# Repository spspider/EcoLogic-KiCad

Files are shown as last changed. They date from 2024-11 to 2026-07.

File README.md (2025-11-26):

# EcoLogic KiCad - ESP8266 Home Automation PCB

A professional-grade KiCad project for ESP8266-based home automation systems, designed for PCBWAY manufacturing and Home Assistant integration.

you can control your device throw this site:
[https://ecologic.pp.ua/iot-manager/](https://ecologic.pp.ua/iot-manager/)
Register as a new user and go to "Devices"

## 📋 Project Overview

This repository contains complete PCB designs for IoT home automation controllers using ESP8266 microcontrollers. The boards are optimized for controlling lights, home appliances, and other smart devices through Home Assistant.

### Key Features
- ESP8266-based design for WiFi connectivity
- Multiple relay outputs for appliance control
- PCBWAY-ready manufacturing files
- Home Assistant compatible
- Professional PCB layout with proper isolation
- SMD components for compact design

## 🖼️ Board Images

| Schematic | PCB Layout |
|---|---|
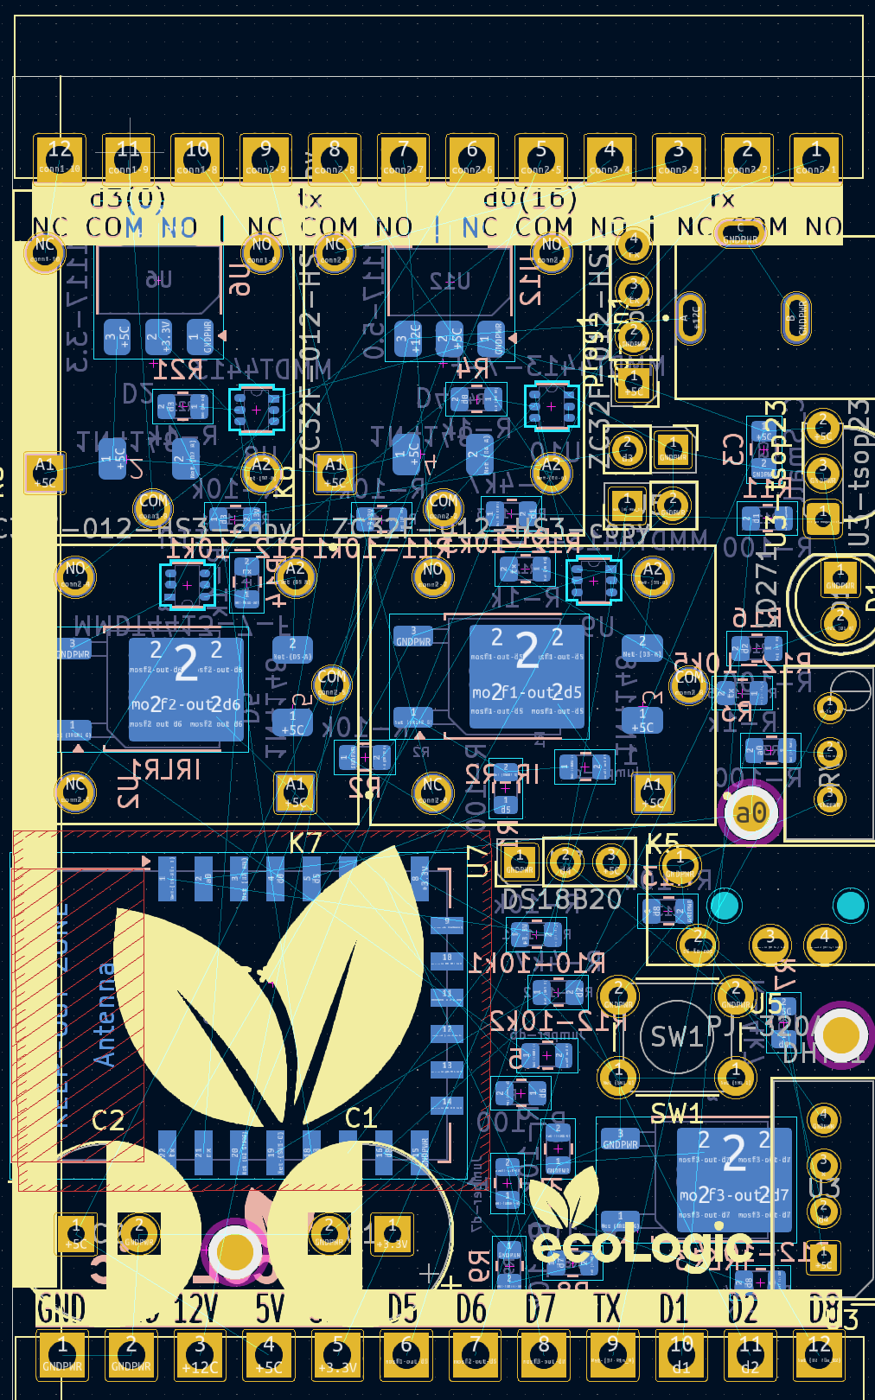
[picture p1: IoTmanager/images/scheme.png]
Schematic
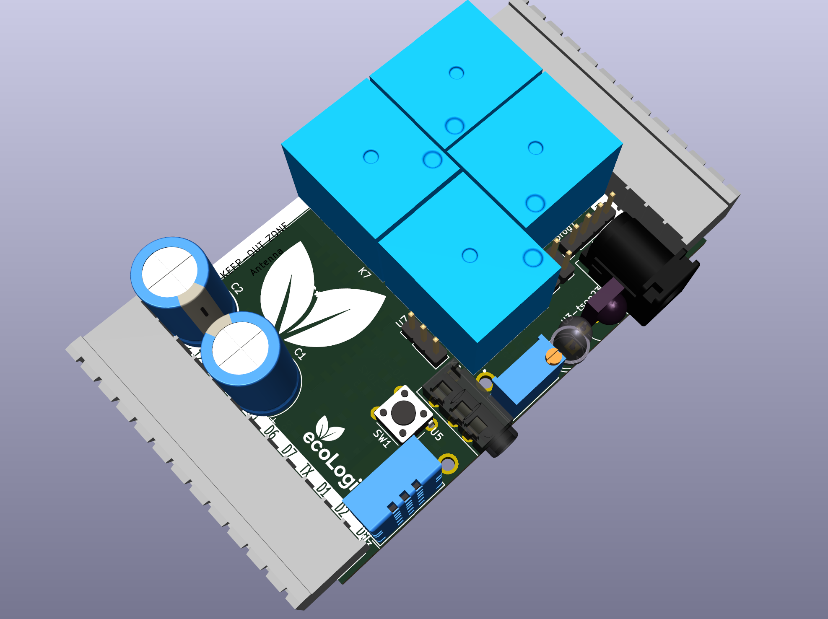
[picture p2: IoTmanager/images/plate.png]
PCB Top
|  |  |
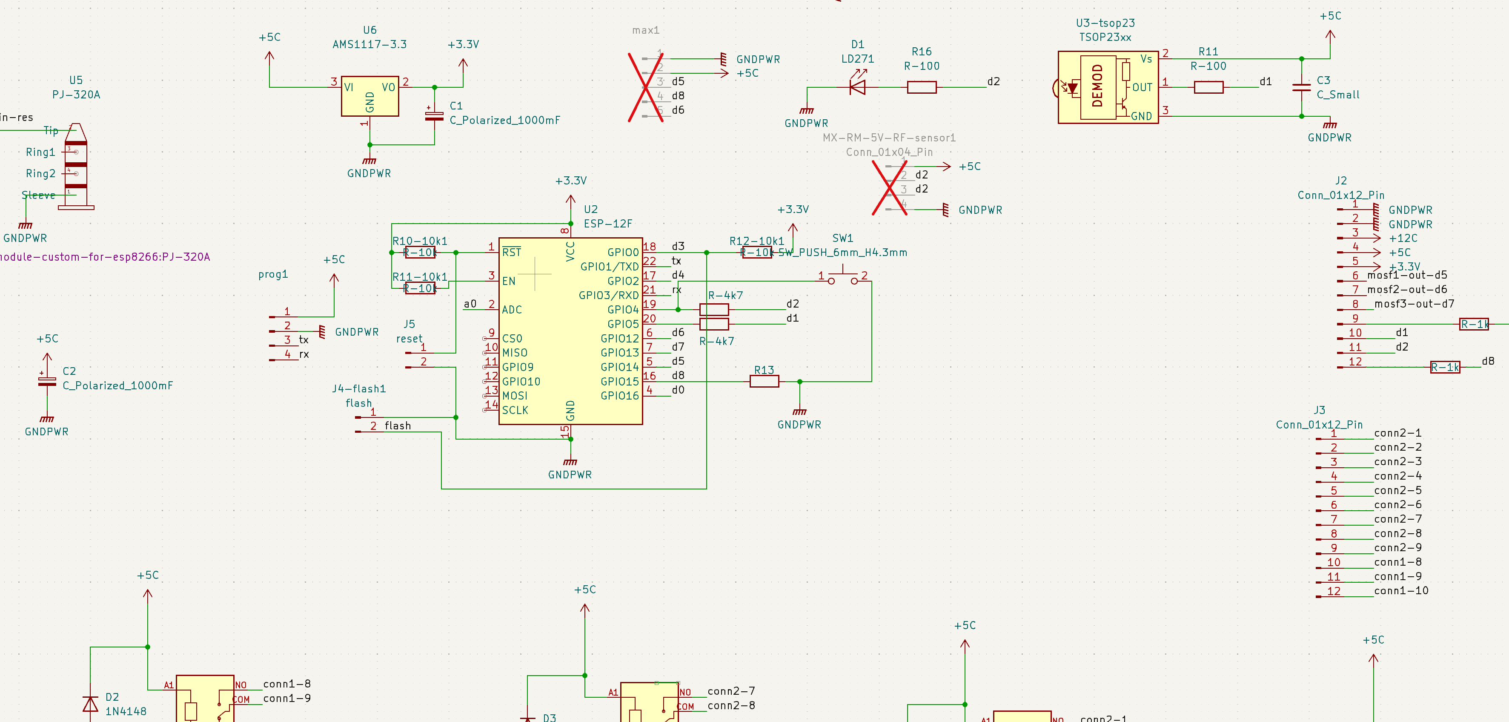
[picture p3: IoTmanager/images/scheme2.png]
Schematic v2
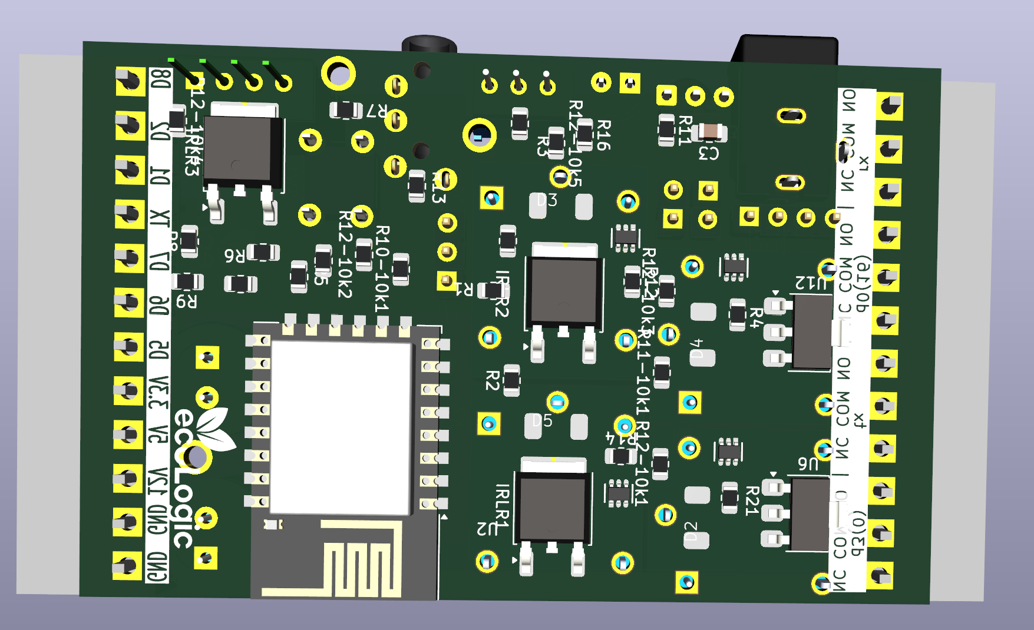
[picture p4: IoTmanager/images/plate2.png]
PCB Bottom
|  |  |

## 📁 Repository Structure

```
EcoLogic-KiCad/
├── IoTmanager/                    # Main project directory
│   ├── BOM-CPL/                   # Bill of Materials & Component Placement
│   │   ├── BOM.csv               # PCBWAY Bill of Materials
│   │   ├── CPL.xlsx              # Component Placement List
│   │   └── *.csv                 # Position files
│   ├── gerber/                    # Manufacturing files
│   │   ├── gerber.zip            # Complete gerber package
│   │   ├── *.gbr                 # Individual gerber layers
│   │   └── *.drl                 # Drill files
│   ├── images/                    # PCB and schematic images
│   ├── LCPCB/                     # PCBWAY templates
│   └── *.kicad_*                 # KiCad project files
└── README.md                      # This file
```

## 🔧 Bill of Materials (BOM)

| Reference | Component | Quantity | Description |
|---|---|---|---|
| U2 | ESP-12F | 1 | ESP8266 WiFi Module |
| U6 | AMS1117-3.3 | 1 | 3.3V Voltage Regulator |
| U12 | AMS1117-5.0 | 1 | 5.0V Voltage Regulator |
| U3 | DHT11 | 1 | Temperature & Humidity Sensor |
| U7 | DS18B20 | 1 | Temperature Sensor |
| U5 | PJ-320A | 1 | Audio Jack Connector |
| Q1,Q3,Q5,Q7 | MMBT5401 | 4 | PNP Transistors |
| Q2,Q4,Q6,Q8 | MMBT5551-npn | 4 | NPN Transistors |
| K3,K5,K6,K7 | ZC32F-012-HS3 | 4 | 12V Relays |
| D1 | LD271 | 1 | LED Indicator |
| D2,D3,D4,D5 | 1N4148 | 4 | Switching Diodes |
| C1,C2 | 1000µF | 2 | Polarized Capacitors |
| C4 | 10µF | 1 | Polarized Capacitor |
| C3 | 100nF | 1 | Ceramic Capacitor |
| R1,R5,R8,R11,R16 | 100Ω | 5 | Current Limiting Resistors |
| R3,R4,R12,R14-R19 | 1kΩ | 10 | Base Resistors |
| R2,R6,R9,R10,R13 | 10kΩ | 8 | Pull-up Resistors |
| R7 | 4.7kΩ | 1 | Pull-up Resistor |
| 33R1 | 33Ω | 1 | Current Limiting Resistor |
| J1 | Power Relay | 1 | Main Power Connector |
| J2,J3 | 12-Pin Connector | 2 | I/O Connectors |
| J4 | Flash Connector | 1 | Programming Interface |
| J5 | Reset Button | 1 | System Reset |
| SW1 | Push Button | 1 | 6mm Tactile Switch |
| Jumper-d5,d6,d7 | Jumpers | 3 | Configuration Jumpers |

## 🏭 PCBway Manufacturing Guide

### Step 1: Prepare Files
1. Download the complete `gerber.zip` from `IoTmanager/gerber/`
2. Get BOM file: `IoTmanager/BOM-CPL/BOM.csv`
3. Get CPL file: `IoTmanager/BOM-CPL/CPL.xlsx`

### Step 2: Upload to PCBWAY
1. Go to [www.pcbway.com](https://www.pcbway.com/QuickOrderOnline.aspx)
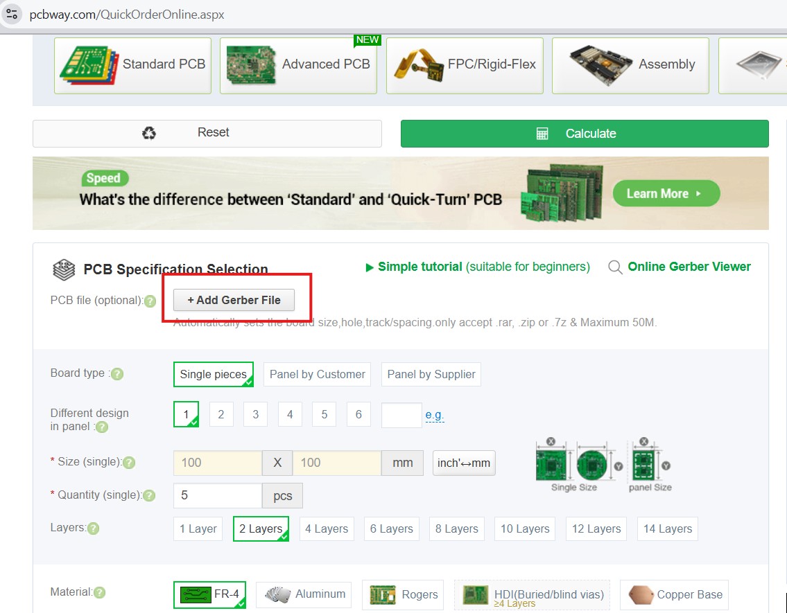
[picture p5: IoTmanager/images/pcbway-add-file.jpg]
pcbway add schematic

2. Click "Add gerber file" and upload `gerber2.zip`
3. Review PCB specifications, dont change anything:
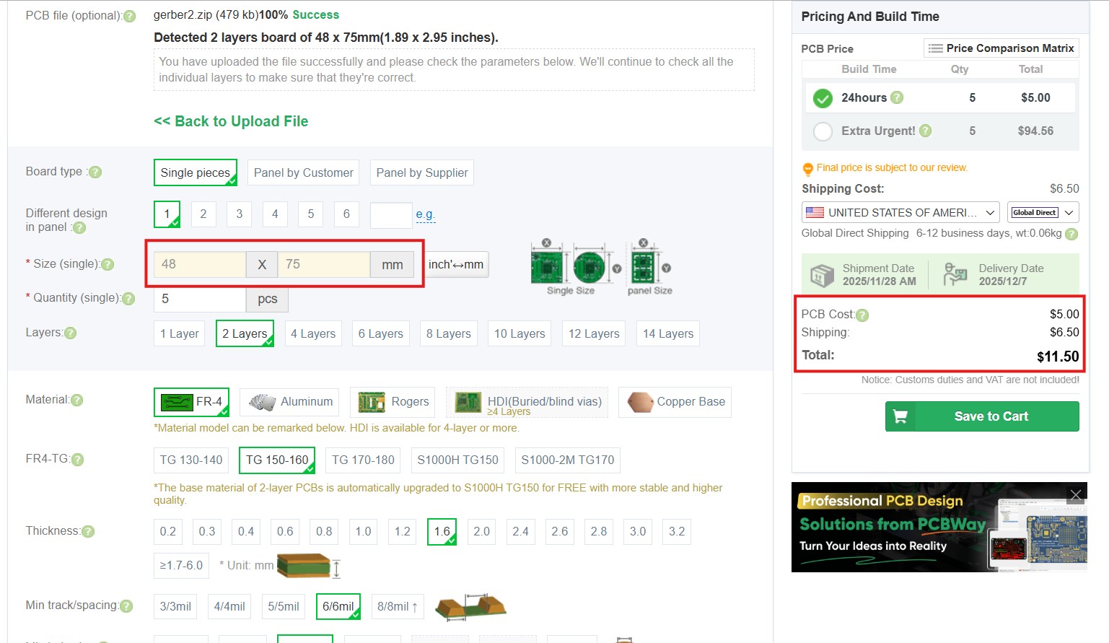
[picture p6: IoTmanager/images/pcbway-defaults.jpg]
review


   - **Layers**: 2
   - **Thickness**: 1.6mm
   - **Color**: Green (recommended)
   - **Surface Finish**: HASL (lead-free)

### Step 3: SMT Assembly (Optional)
1. Enable "SMT Assembly"
2. Upload BOM file (`BOM.csv`)
3. Upload CPL file (`CPL.xlsx`)
4. Review component placement
5. Confirm parts availability

### Step 4: Order
- Minimum quantity: 5 pieces
- Typical lead time: 2-5 days (PCB only)
- SMT assembly adds 3-5 days

## ⚡ Power Requirements

| Parameter | Value | Notes |
|---|---|---|
| Input Voltage | 5V DC | Via USB or external supply |
| Current Consumption | 80-200mA | Depends on relay states |
| Relay Switching | 10A @ 250V AC | Per relay channel |
| Logic Level | 3.3V | ESP8266 native |

## 🛠️ Assembly Tips

### Soldering Guidelines
- Use lead-free solder (SAC305 recommended)
- Soldering iron: 350°C for SMD components
- Use flux for better joints
- Solder ESP8266 module first

### Testing Procedure
1. **Visual Inspection**: Check for shorts and proper alignment
2. **Power Test**: Apply 5V and measure 3.3V rail
3. **Programming Test**: Upload basic blink sketch
4. **Relay Test**: Verify relay switching with multimeter

## 🚨 Safety Warnings

⚠️ **HIGH VOLTAGE WARNING**
- Relays switch mains voltage (110V/220V AC)
- Always disconnect power before wiring
- Use proper electrical enclosure
- Follow local electrical codes

⚠️ **ESD Precautions**
- Use anti-static wrist strap during assembly
- Store boards in anti-static bags
- Ground yourself before handling

## 📝 Version History

| Version | Date | Changes |
|---|---|---|
| v2 | 2025-07 | Improved routing, added protection circuits |
| v1 | 2025-05 | Initial release |

## 🤝 Contributing

1. Fork the repository
2. Create feature branch (`git checkout -b feature/improvement`)
3. Commit changes (`git commit -am 'Add improvement'`)
4. Push to branch (`git push origin feature/improvement`)
5. Create Pull Request

## 📄 License

This project is open-source hardware. Feel free to modify and distribute according to your needs.

## 🆘 Support & Donations

If this project helped you, consider supporting the development:



**Other ways to support:**
- ⭐ Star this repository
- 🐛 Report bugs and issues
- 💡 Suggest improvements
- 📖 Improve documentation
---

**Made with ❤️ for the Home Automation Community**

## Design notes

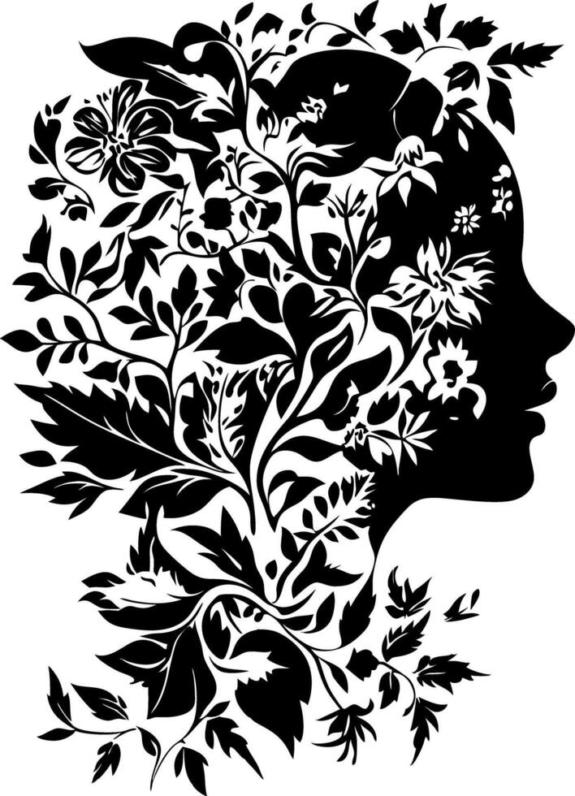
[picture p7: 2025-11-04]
IoTmanager/images/floral-silhouette-human-profile-intricate-botanical-design-for-art-and-tattoo-vector.jpg

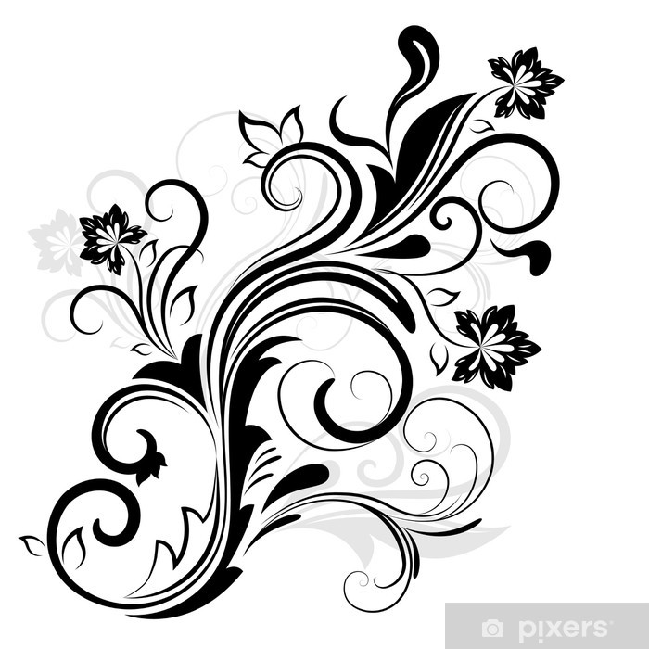
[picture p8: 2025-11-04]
IoTmanager/images/stickers-black-and-white-floral-design-element-isolated-on-white.jpg

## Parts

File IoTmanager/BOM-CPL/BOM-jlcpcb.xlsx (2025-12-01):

Designator | Comment | Footprint | JLCPCB Part #
C3 | 22uF | Capacitor_SMD:C_0805_2012Metric_Pad1.18x1.45mm_HandSolder | C45783
R33 | R-4k7 | Resistor_SMD:R_0805_2012Metric | C17673
R30 | R-4k7 | Resistor_SMD:R_0805_2012Metric | C17673
R26 | R-4k7 | Resistor_SMD:R_0805_2012Metric | C17673
R17 | R-4k7 | Resistor_SMD:R_0805_2012Metric | C17673
R3 | R-4k7 | Resistor_SMD:R_0805_2012Metric | C17673
R29 | 33R | Resistor_SMD:R_0805_2012Metric | C17634
R11 | 33R | Resistor_SMD:R_0805_2012Metric | C17634
R25 | R-1k | Resistor_SMD:R_0805_2012Metric | C17513
R24 | R-1k | Resistor_SMD:R_0805_2012Metric | C17513
R23 | R-1k-opt | Resistor_SMD:R_0805_2012Metric | C17513
R22 | R-1k | Resistor_SMD:R_0805_2012Metric | C17513
R20 | R-1k | Resistor_SMD:R_0805_2012Metric | C17513
R18 | R-1k | Resistor_SMD:R_0805_2012Metric | C17513
R13 | R-1k | Resistor_SMD:R_0805_2012Metric | C17513
R12 | R-1k | Resistor_SMD:R_0805_2012Metric | C17513
R10 | R-1k | Resistor_SMD:R_0805_2012Metric | C17513
R7 | R-1k | Resistor_SMD:R_0805_2012Metric | C17513
R4 | R-1k | Resistor_SMD:R_0805_2012Metric | C17513
R2 | R-1k | Resistor_SMD:R_0805_2012Metric | C17513
R1 | R-1k | Resistor_SMD:R_0805_2012Metric | C17513
R34 | R-10k | Resistor_SMD:R_0805_2012Metric | C17414
R32 | R-10k | Resistor_SMD:R_0805_2012Metric | C17414
R28 | R-10k | Resistor_SMD:R_0805_2012Metric | C17414
R27 | R-10k | Resistor_SMD:R_0805_2012Metric | C17414
R21 | R-10k | Resistor_SMD:R_0805_2012Metric | C17414
R9 | R-10k | Resistor_SMD:R_0805_2012Metric | C17414
R8 | R-10k | Resistor_SMD:R_0805_2012Metric | C17414
R6 | R-10k | Resistor_SMD:R_0805_2012Metric | C17414
R5 | R-10k-opt | Resistor_SMD:R_0805_2012Metric | C17414
R19 | R-100 | Resistor_SMD:R_0805_2012Metric | C17408
R14 | R-100 | Resistor_SMD:R_0805_2012Metric | C17408
C4 | 10uF | Capacitor_SMD:C_0805_2012Metric_Pad1.18x1.45mm_HandSolder | C15850

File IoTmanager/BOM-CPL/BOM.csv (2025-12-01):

Reference | Value | Footprint | Qty | JLCPCB Part
C3 | 22uF | Capacitor_SMD:C_0805_2012Metric_Pad1.18x1.45mm_HandSolder | 1 | C45783
R33 | R-4k7 | Resistor_SMD:R_0805_2012Metric | 1 | C17673
R30 | R-4k7 | Resistor_SMD:R_0805_2012Metric | 1 | C17673
R26 | R-4k7 | Resistor_SMD:R_0805_2012Metric | 1 | C17673
R17 | R-4k7 | Resistor_SMD:R_0805_2012Metric | 1 | C17673
R3 | R-4k7 | Resistor_SMD:R_0805_2012Metric | 1 | C17673
R29 | 33R | Resistor_SMD:R_0805_2012Metric | 1 | C17634
R11 | 33R | Resistor_SMD:R_0805_2012Metric | 1 | C17634
R25 | R-1k | Resistor_SMD:R_0805_2012Metric | 1 | C17513
R24 | R-1k | Resistor_SMD:R_0805_2012Metric | 1 | C17513
R23 | R-1k-opt | Resistor_SMD:R_0805_2012Metric | 1 | C17513
R22 | R-1k | Resistor_SMD:R_0805_2012Metric | 1 | C17513
R20 | R-1k | Resistor_SMD:R_0805_2012Metric | 1 | C17513
R18 | R-1k | Resistor_SMD:R_0805_2012Metric | 1 | C17513
R13 | R-1k | Resistor_SMD:R_0805_2012Metric | 1 | C17513
R12 | R-1k | Resistor_SMD:R_0805_2012Metric | 1 | C17513
R10 | R-1k | Resistor_SMD:R_0805_2012Metric | 1 | C17513
R7 | R-1k | Resistor_SMD:R_0805_2012Metric | 1 | C17513
R4 | R-1k | Resistor_SMD:R_0805_2012Metric | 1 | C17513
R2 | R-1k | Resistor_SMD:R_0805_2012Metric | 1 | C17513
R1 | R-1k | Resistor_SMD:R_0805_2012Metric | 1 | C17513
R34 | R-10k | Resistor_SMD:R_0805_2012Metric | 1 | C17414
R32 | R-10k | Resistor_SMD:R_0805_2012Metric | 1 | C17414
R28 | R-10k | Resistor_SMD:R_0805_2012Metric | 1 | C17414
R27 | R-10k | Resistor_SMD:R_0805_2012Metric | 1 | C17414
R21 | R-10k | Resistor_SMD:R_0805_2012Metric | 1 | C17414
R9 | R-10k | Resistor_SMD:R_0805_2012Metric | 1 | C17414
R8 | R-10k | Resistor_SMD:R_0805_2012Metric | 1 | C17414
R6 | R-10k | Resistor_SMD:R_0805_2012Metric | 1 | C17414
R5 | R-10k-opt | Resistor_SMD:R_0805_2012Metric | 1 | C17414
R19 | R-100 | Resistor_SMD:R_0805_2012Metric | 1 | C17408
R14 | R-100 | Resistor_SMD:R_0805_2012Metric | 1 | C17408
C4 | 10uF | Capacitor_SMD:C_0805_2012Metric_Pad1.18x1.45mm_HandSolder | 1 | C15850
U8 | PJ-320A | module-custom-for-esp8266:PJ-320A | 1
U7 | ESP-12F | module-custom-for-esp8266:ESP-12E_no_pins | 1
U6 | TSOP1838 | module-custom-for-esp8266:TSOP18XX | 1
U5 | Mini360 | module-custom-for-esp8266:mini360 | 1
U4 | AMS1117-3.3 | Package_TO_SOT_SMD:SOT-223-3_TabPin2 | 1
U2 | AMS1117-5.0 | Package_TO_SOT_SMD:SOT-223-3_TabPin2 | 1
U1 | DHT11 | Sensor:Aosong_DHT11_5.5x12.0_P2.54mm | 1
SW2-reset1 | SW_PUSH_6mm_H4.3mm | module-custom-for-esp8266:SW_PUSH_6mm_H4.3mm | 1
SW2-flash1 | SW_PUSH_6mm_H4.3mm | module-custom-for-esp8266:SW_PUSH_6mm_H4.3mm | 1
SW1 | SW_PUSH_6mm_H4.3mm | module-custom-for-esp8266:SW_PUSH_6mm_H4.3mm | 1
R31 | d3-as-input | Resistor_SMD:R_0805_2012Metric | 1
R16 | rx-as-input | Resistor_SMD:R_0805_2012Metric | 1
Q10 | FDS9926A | Package_SO:SOIC-8_3.9x4.9mm_P1.27mm | 1
Q9 | FDS9926A | Package_SO:SOIC-8_3.9x4.9mm_P1.27mm | 1
Q8 | G1 | Package_TO_SOT_SMD:SOT-23 | 1
Q7 | 2L | Package_TO_SOT_SMD:SOT-23 | 1
Q6 | G1 | Package_TO_SOT_SMD:SOT-23 | 1
Q5 | 2L | Package_TO_SOT_SMD:SOT-23 | 1
Q4 | G1 | Package_TO_SOT_SMD:SOT-23 | 1
Q3 | 2L | Package_TO_SOT_SMD:SOT-23 | 1
Q2 | G1 | Package_TO_SOT_SMD:SOT-23 | 1
Q1 | 2L | Package_TO_SOT_SMD:SOT-23 | 1
prog1 | prog | Connector_PinHeader_2.54mm:PinHeader_1x04_P2.54mm_Vertical | 1
K4 | RELAY_SRD-05VDC | module-custom-for-esp8266:RELAY_SRD-05VDC-SL-C | 1
K3 | RELAY_SRD-05VDC | module-custom-for-esp8266:RELAY_SRD-05VDC-SL-C | 1
K2 | RELAY_SRD-05VDC | module-custom-for-esp8266:RELAY_SRD-05VDC-SL-C | 1
K1 | RELAY_SRD-05VDC | module-custom-for-esp8266:RELAY_SRD-05VDC-SL-C | 1
J6 | Conn_01x12_Pin | module-custom-for-esp8266:connector-12-green-mini | 1
J5 | Conn_01x12_Pin | module-custom-for-esp8266:connector-12-green-mini | 1
J1 | powerRelay | Connector_PinHeader_2.54mm:PinHeader_1x02_P2.54mm_Vertical | 1
F1 | Polyfuse_Small | Fuse:Fuse_1812_4532Metric | 1
dc-in1 | ~ | module-custom-for-esp8266:5.5PowerIn | 1
D14 | BZV55B3V3 | Diode_SMD:D_MiniMELF | 1
D13 | BZV55B3V3 | Diode_SMD:D_MiniMELF | 1
D12 | BZV55B3V3 | Diode_SMD:D_MiniMELF | 1
D11 | BZV55B3V3 | Diode_SMD:D_MiniMELF | 1
D10 | BZV55B3V3 | Diode_SMD:D_MiniMELF | 1
D9 | SM6T3.3A-3.3V | Diode_SMD:D_SMB | 1
D8 | 1N4148 | Diode_SMD:D_MiniMELF | 1
D6 | 1N4148 | Diode_SMD:D_MiniMELF | 1
D5 | LD271 | LED_THT:LED_D5.0mm_IRGrey | 1
D4 | SM6T24A-12V | Diode_SMD:D_SMB | 1
D3 | 1N4148 | Diode_SMD:D_MiniMELF | 1
D2 | 1N4148 | Diode_SMD:D_MiniMELF | 1
D1 | SM6T24A | Diode_SMD:D_SMB | 1
C2 | C_Polarized_Small | Capacitor_THT:CP_Radial_D10.0mm_P3.50mm | 1
C1 | C_Polarized_Small | Capacitor_THT:CP_Radial_D10.0mm_P3.50mm | 1

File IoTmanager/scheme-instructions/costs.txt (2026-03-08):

списание с карты июль 2025 покупки на таобао, цена компонентов из магазинов вместе с доставкой RON

5.44
7.32
59.46
6.97
7.38
5.85
13.17
4.63
17.19
7.88
18.16
11.19

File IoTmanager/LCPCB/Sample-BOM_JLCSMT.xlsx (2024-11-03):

Comment | Designator | Footprint | JLCPCB Part #（optional）
100uF | C1 | CAP-SMD_L3.5-W2.8 | C16133
15K | R5,R6 | R0603 | C22809
DC-005-20A_C136744 | DC1 | DC-IN-TH_DC-005-20A | C136744
Header-Female-2.54_1x8 | P2,P3 | HDR-TH_8P-P2.54-V | C27438
K2-1102DP-C4SW-04 | SW1 | KEY-TH_4P-L6.0-W6.0-P4.50-LS6.5 | C110153
ATMEGA328P-PU | U1 | DIP-28_L34.6-W7.3-P2.54-LS10.2-BL | C33901
670688000 | USB1 | USB-B-TH_67068-8000 | C114097

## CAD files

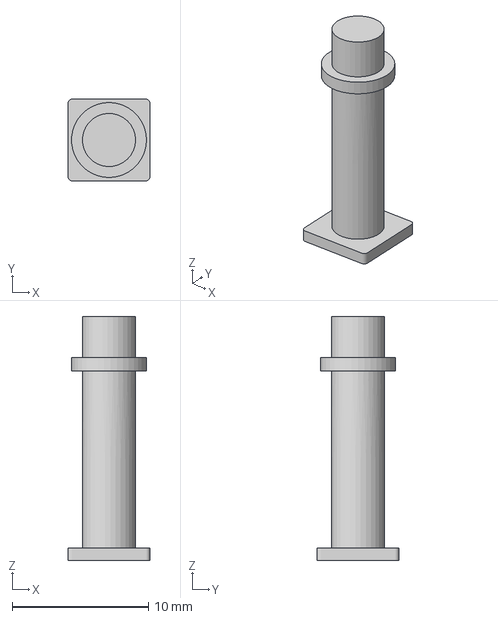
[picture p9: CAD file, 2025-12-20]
IoTmanager/3d-model/btn.3mf
6.00 x 6.00 x 17.9 mm

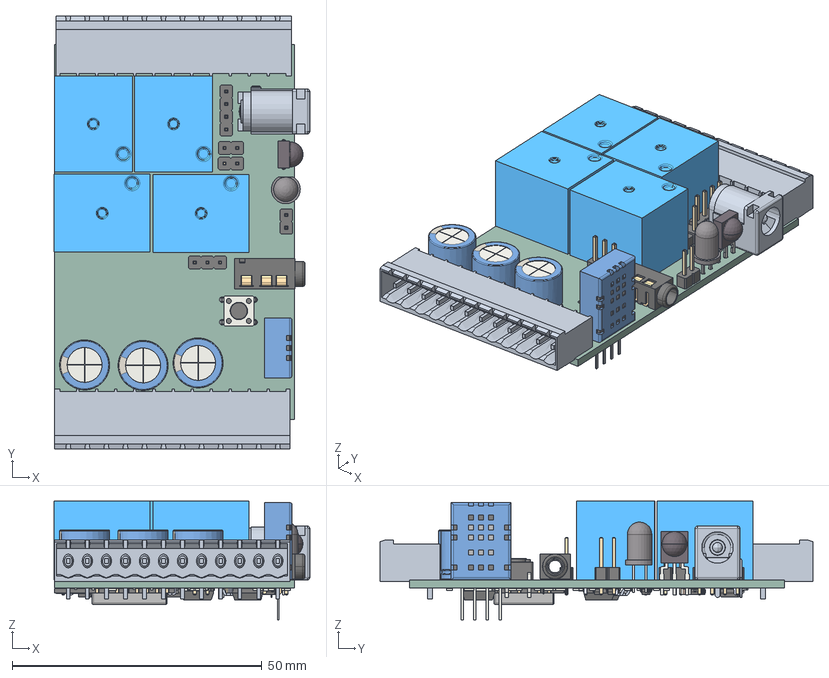
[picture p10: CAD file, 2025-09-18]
IoTmanager/IoTmanager_v2.step
51.1 x 86.6 x 23.8 mm
PinHeader_1x03_P254mm_Vertical
LED_D5.0mm_IRGrey
Vishay_MINIMOLD-3pin
SRD-12VDC-SL-C x 4
CP_Radial_D100mm_P350mm x 3
SW_PUSH_6mm_h4.3mm
C-1-796638-2 x 2
PinHeader_1x04_P254mm_Vertical
PinHeader_1x02_P254mm_Vertical x 3
PJ320A
Aosong_DHT11_5.5x12.0_P2.54mm
R_0805_2012Metric x 31
SOT_23 x 8
CQ assembly x 3
ESP_12E001_cp
SOT_223 x 2
C_0805_2012Metric
IoTmanager-v2_PCB

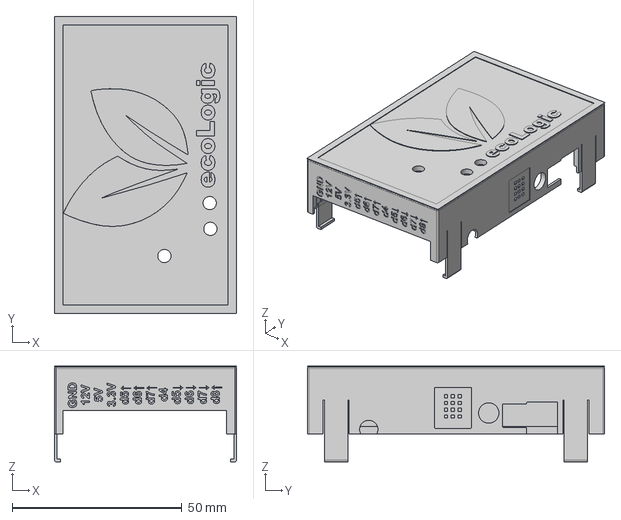
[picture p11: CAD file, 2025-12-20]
IoTmanager/3d-model/lid.step
53.6 x 87.6 x 28.2 mm

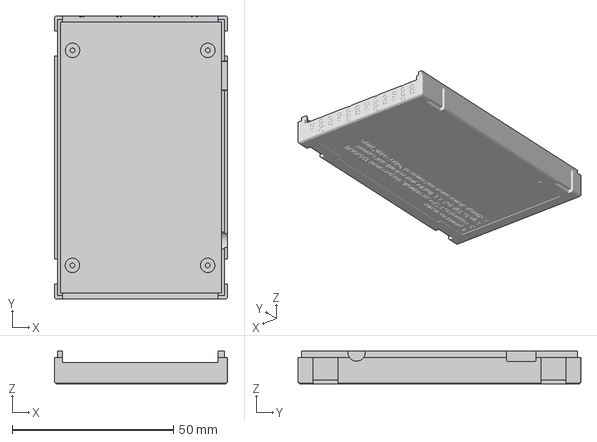
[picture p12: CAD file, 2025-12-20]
IoTmanager/3d-model/base.3mf
53.6 x 87.6 x 10.2 mm

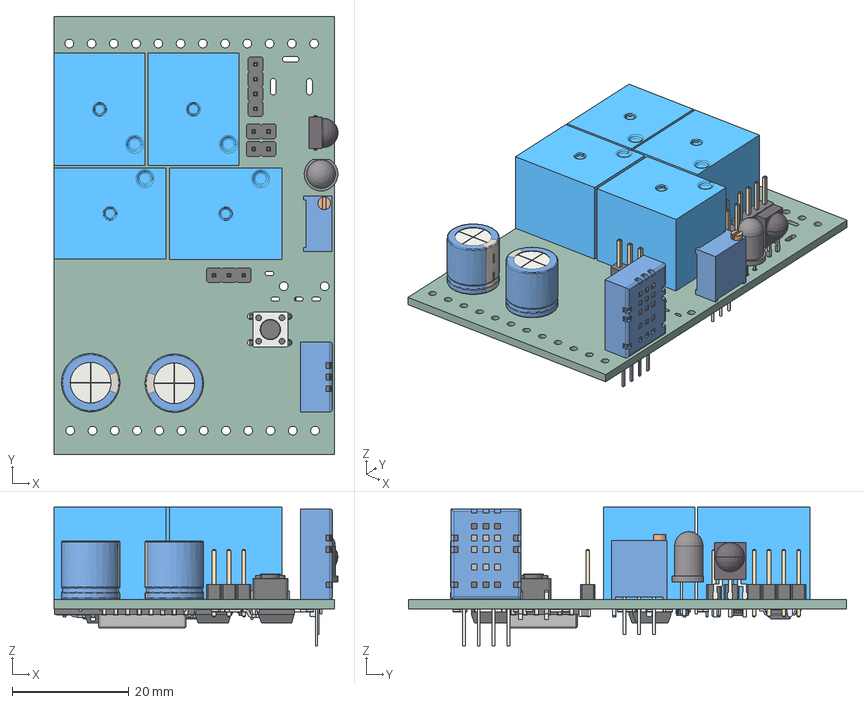
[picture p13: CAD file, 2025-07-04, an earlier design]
IoTmanager/IoTmanager.step
48.6 x 75.0 x 23.8 mm
PinHeader_1x03_P254mm_Vertical
Potentiometer_Bourns_3296W_Vertical
LED_D5.0mm_IRGrey
Vishay_MINIMOLD-3pin
SRD-12VDC-SL-C x 4
SW_PUSH_6mm_h4.3mm
PinHeader_1x04_P254mm_Vertical
CP_Radial_D100mm_P350mm x 2
PinHeader_1x02_P254mm_Vertical x 2
Aosong_DHT11_5.5x12.0_P2.54mm
R_0805_2012Metric x 25
SOT_363_SC_70_6 x 4
CQ assembly x 3
ESP_12E001_cp
SOT_223 x 2
C_0805_2012Metric
IoTmanager-v2_PCB

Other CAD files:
IoTmanager/3d-model/button.step
IoTmanager/3d-model/lid.3mf

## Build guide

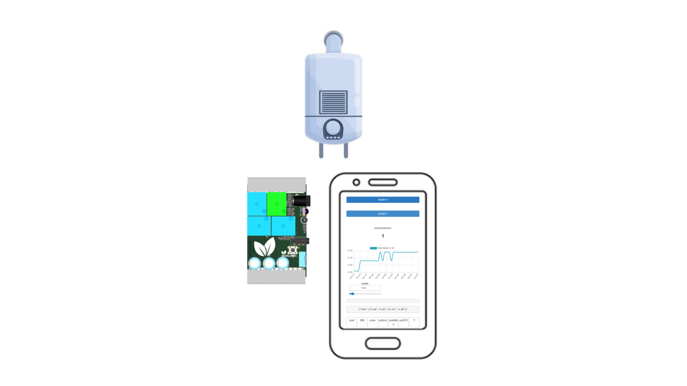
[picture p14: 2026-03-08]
IoTmanager/scheme-instructions/ecologic-warmer.png

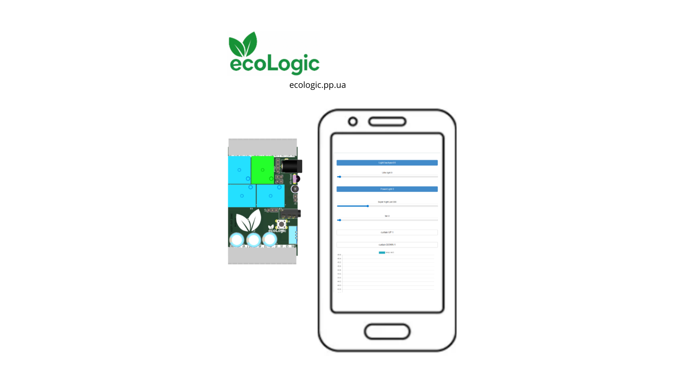
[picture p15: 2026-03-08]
IoTmanager/scheme-instructions/ecologic-ecologic.png

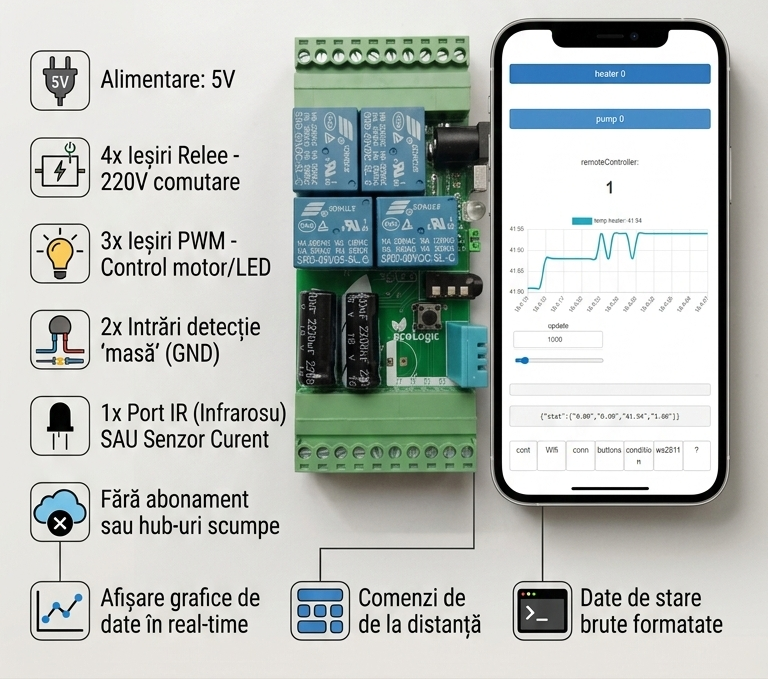
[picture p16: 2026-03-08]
IoTmanager/scheme-instructions/Gemini_Generated_Image_8bum28bum28bum28.png

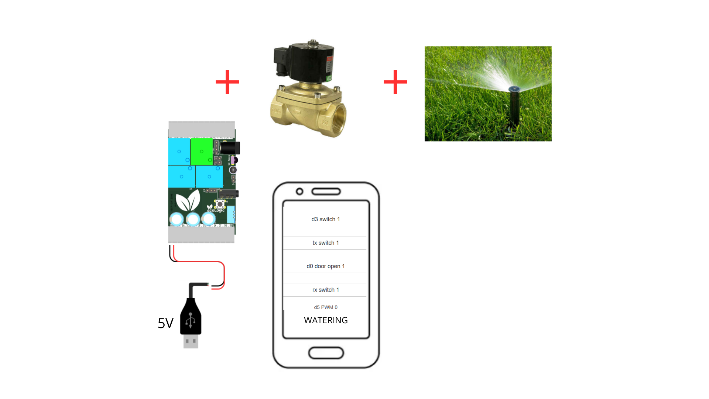
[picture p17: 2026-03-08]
IoTmanager/scheme-instructions/ecologic-water.png

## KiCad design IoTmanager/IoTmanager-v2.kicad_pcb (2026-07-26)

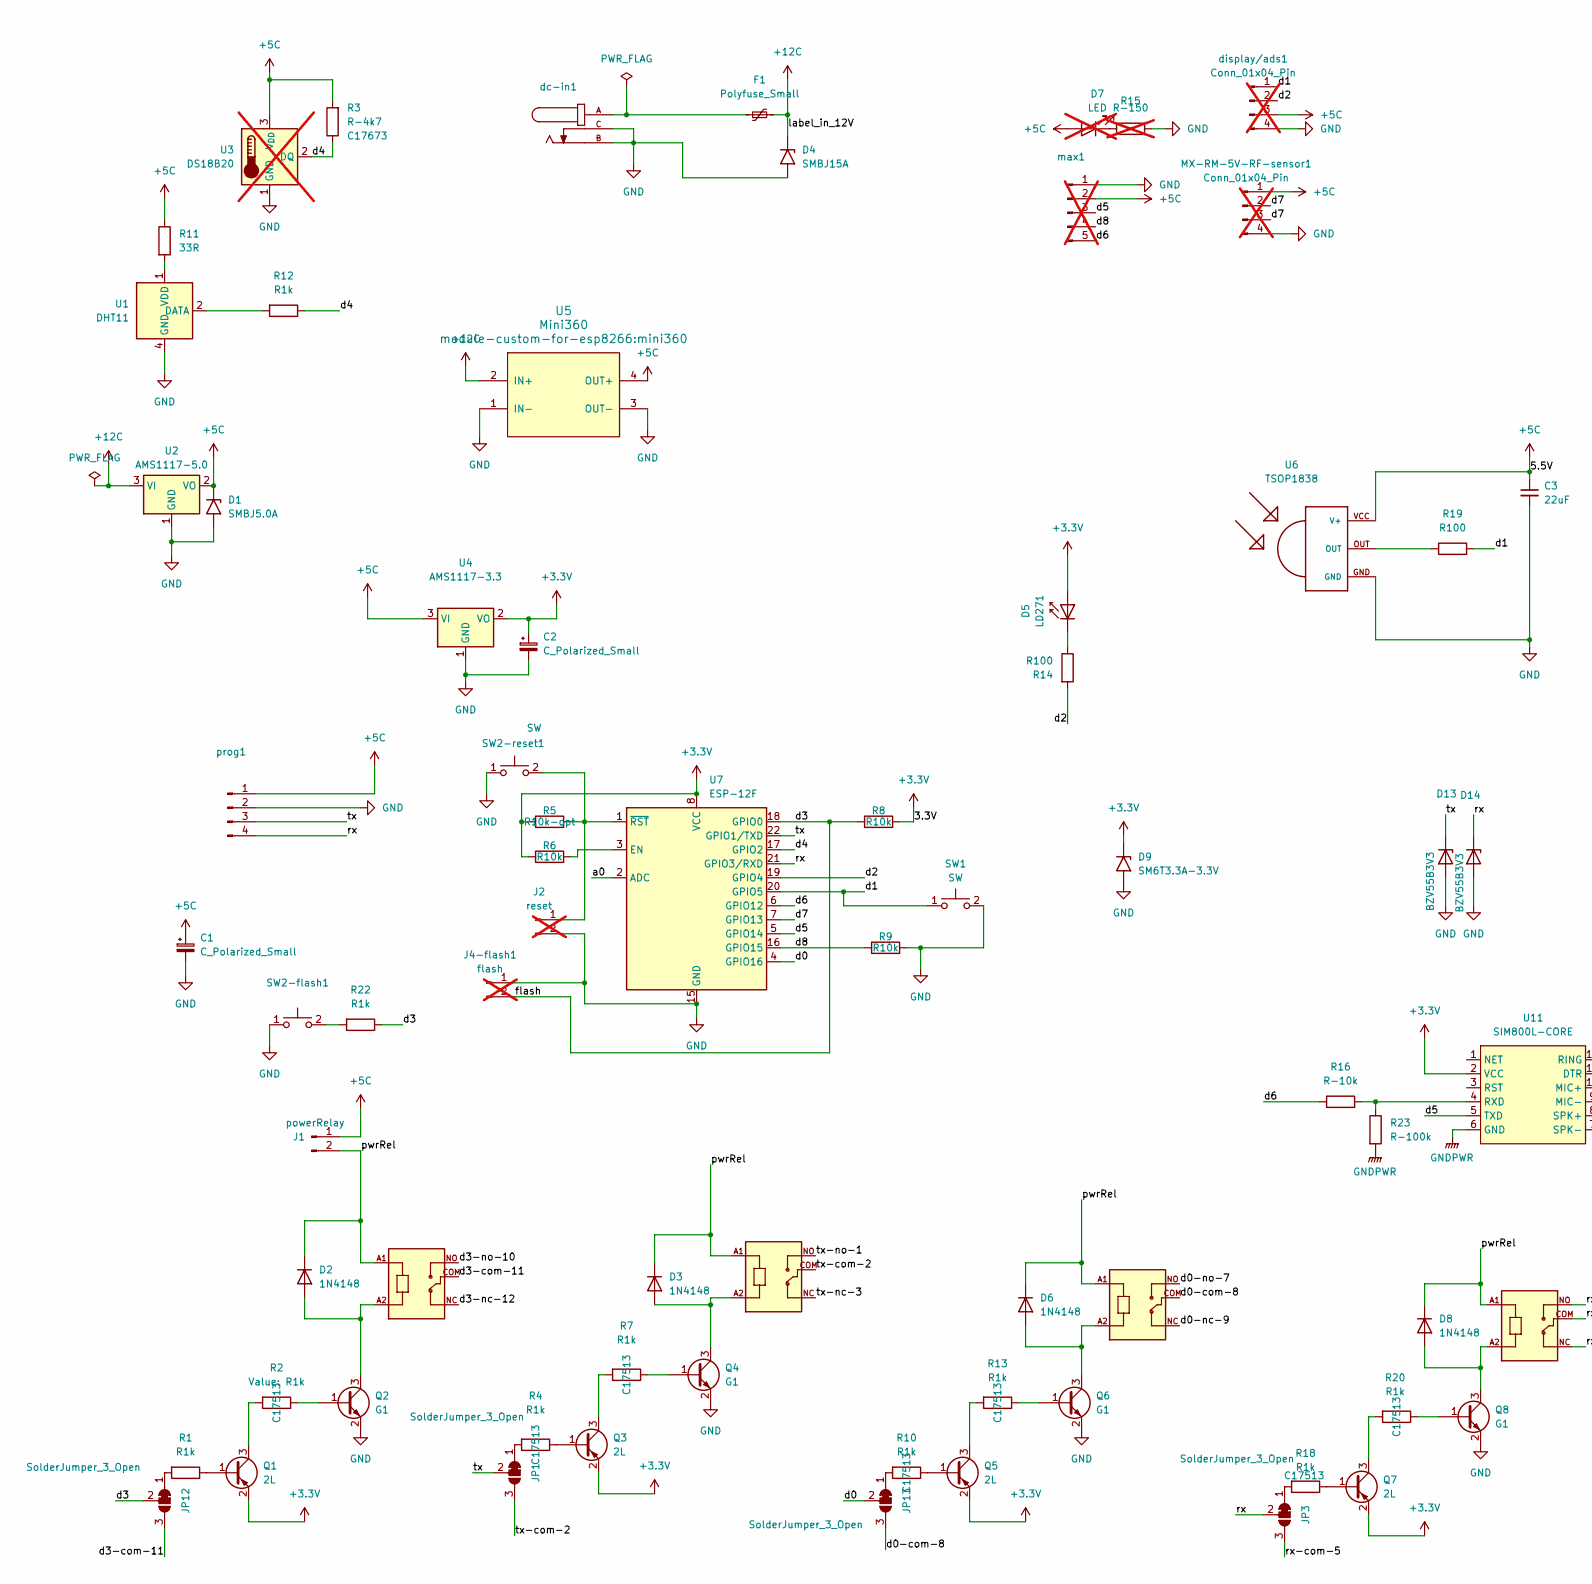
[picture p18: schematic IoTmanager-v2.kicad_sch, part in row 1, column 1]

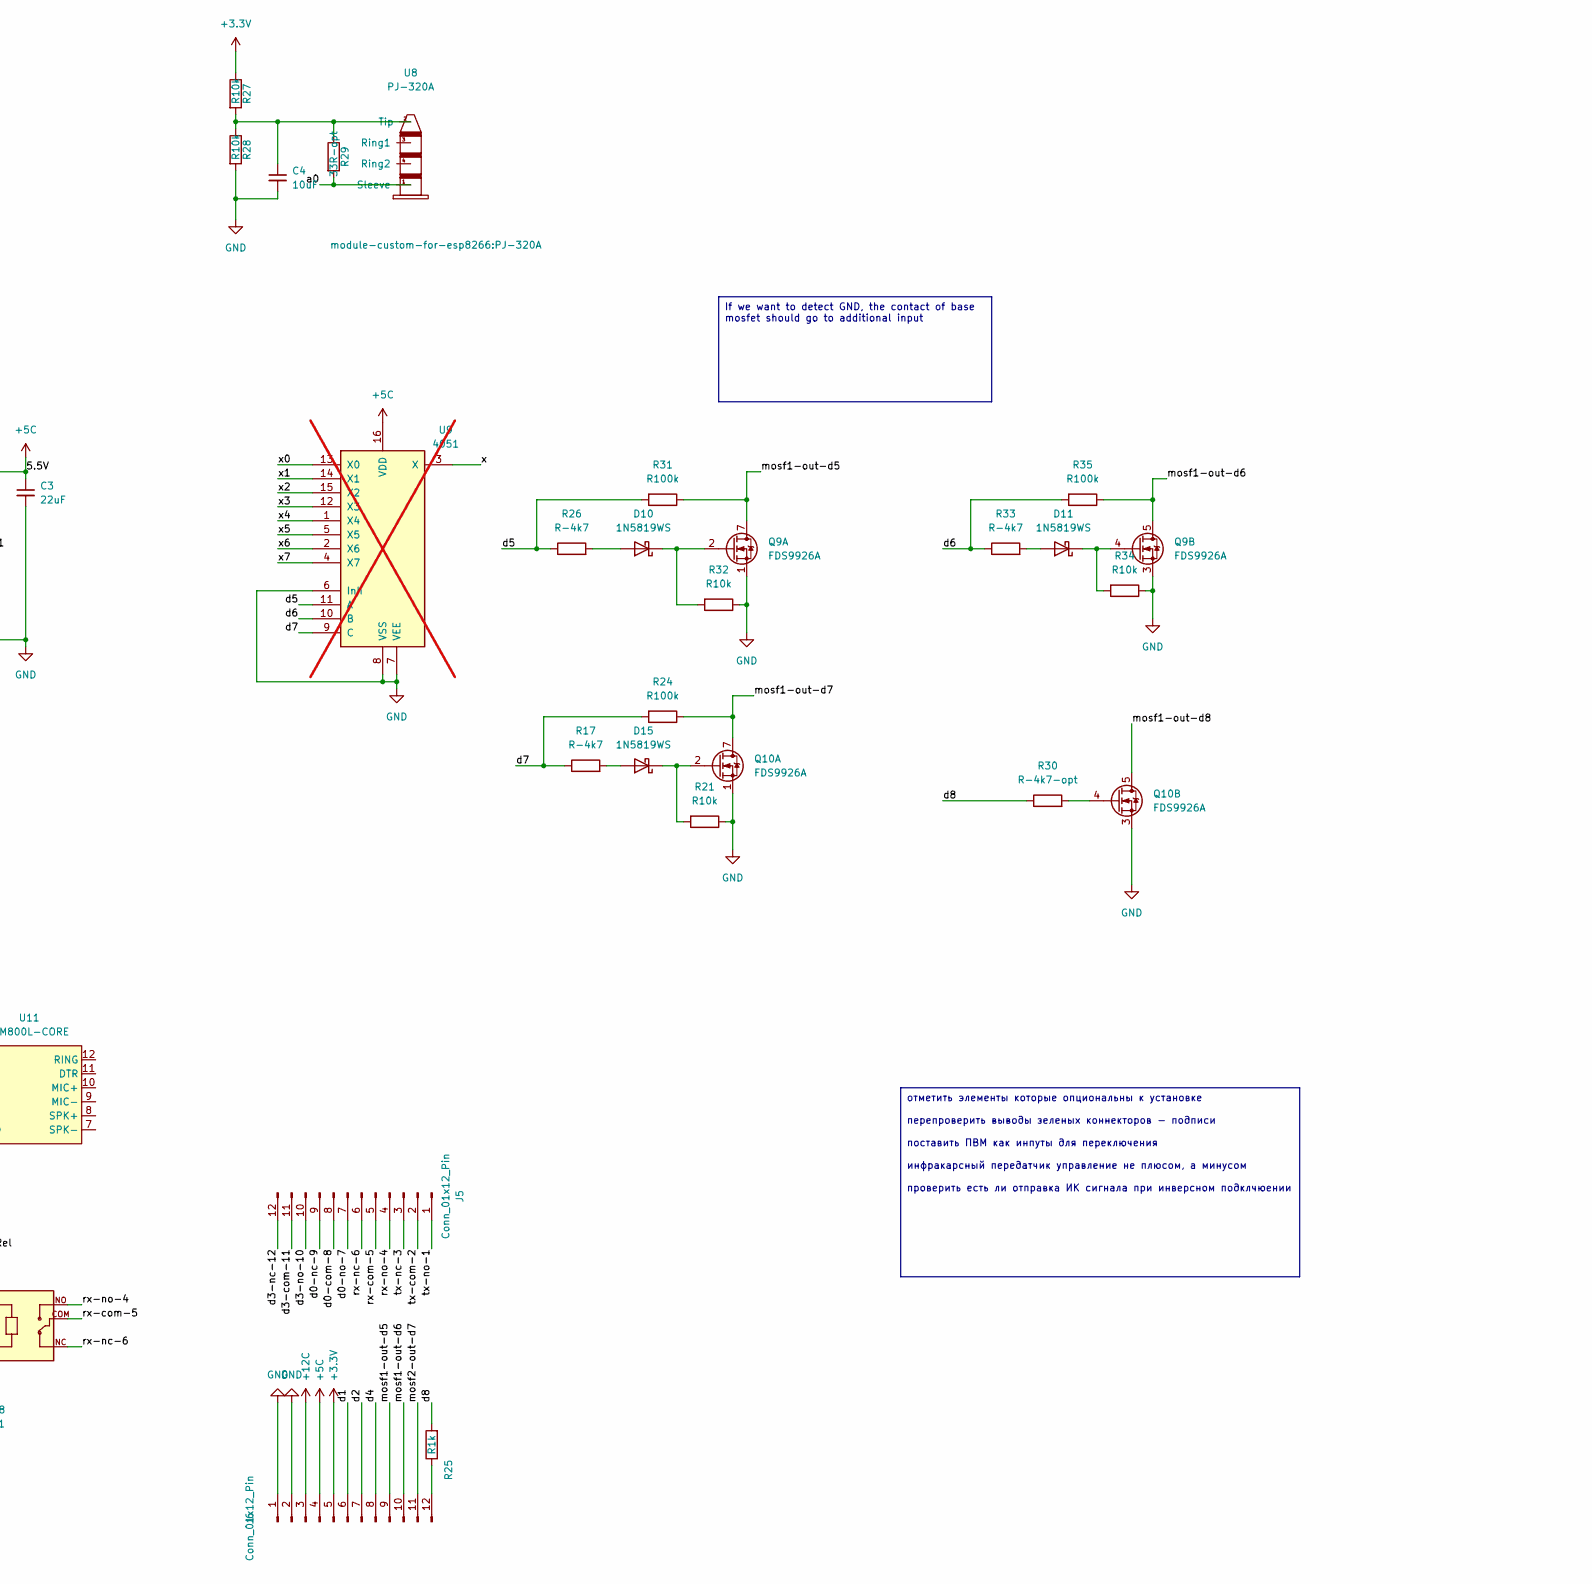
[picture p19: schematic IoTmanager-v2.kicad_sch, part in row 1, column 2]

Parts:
C1, C2: C_Polarized_Small; CP_Radial_D10.0mm_P3.50mm
C3: 22uF; C_0805_2012Metric_Pad1.18x1.45mm_HandSolder; JLCPCB Part C45783
C4: 10uF; C_0805_2012Metric_Pad1.18x1.45mm_HandSolder; JLCPCB Part C15850
D1: SMBJ5.0A; D_SMB
D2, D3, D6, D8: 1N4148; D_MiniMELF
D4: SMBJ15A; D_SMB
D5: LD271; LED_D5.0mm_IRGrey
D7: LED; LED_D5.0mm; not fitted
D9: SM6T3.3A-3.3V; D_SMB
D10, D11, D15: 1N5819WS; D_SOD-123
D13, D14: BZV55B3V3; D_MiniMELF
F1: Polyfuse_Small; Fuse_1812_4532Metric
J1: powerRelay; PinHeader_1x02_P2.54mm_Vertical
J2: reset; PinHeader_1x02_P2.54mm_Vertical; not fitted
J4-flash1: flash; PinHeader_1x02_P2.54mm_Vertical; not fitted
J5, J6: Conn_01x12_Pin; connector-12-green-mini
JP1, JP3, JP12, JP13: SolderJumper_3_Open; SolderJumper-3_P1.3mm_Bridged12_RoundedPad1.0x1.5mm
K1, K2, K3, K4: RELAY_SRD-05VDC; RELAY_SRD-05VDC-SL-C
MX-RM-5V-RF-sensor1: Conn_01x04_Pin; RF_Receiver_433_MHz; not fitted
Q1, Q3, Q5, Q7: 2L; SOT-23; LCSC Part C8326
Q2, Q4, Q6, Q8: G1; SOT-23; LCSC Part C2145
Q9, Q10: FDS9926A; SOIC-8_3.9x4.9mm_P1.27mm
R1, R2, R4, R7, R10, R13, R18, R20, R22: R1k; C_0805_2012Metric_Pad1.18x1.45mm_HandSolder; LCSC Part C25905
R3: R-4k7; C_0805_2012Metric_Pad1.18x1.45mm_HandSolder; JLCPCB Part C17673
R5: R10k-opt; C_0805_2012Metric_Pad1.18x1.45mm_HandSolder; LCSC Part C17414
R6, R8, R9, R27, R28, R32: R10k; C_0805_2012Metric_Pad1.18x1.45mm_HandSolder; LCSC Part C17414
R11: 33R; C_0805_2012Metric_Pad1.18x1.45mm_HandSolder; LCSC Part C17414
R12, R25: R1k; C_0805_2012Metric_Pad1.18x1.45mm_HandSolder; LCSC Part C17414
R14, R19: R100; C_0805_2012Metric_Pad1.18x1.45mm_HandSolder; LCSC Part C17408
R15: R-150; C_0805_2012Metric_Pad1.18x1.45mm_HandSolder; LCSC Part C17408; not fitted
R16: R-10k; R_0805_2012Metric; JLCPCB Part C17414
R17, R26, R33: R-4k7; R_0805_2012Metric; LCSC Part C17408
R21, R34: R10k; R_0805_2012Metric; LCSC Part C17414
R23: R-100k; R_0805_2012Metric; JLCPCB Part C17414
R24, R31, R35: R100k; R_0805_2012Metric; LCSC Part C17414
R29: 33R-opt; C_0805_2012Metric_Pad1.18x1.45mm_HandSolder; LCSC Part C17414
R30: R-4k7-opt; R_0805_2012Metric; LCSC Part C17408
SW1, SW2-flash1, SW2-reset1: SW; SW_PUSH_6mm_H4.3mm
U1: DHT11; Aosong_DHT11_5.5x12.0_P2.54mm
U2: AMS1117-5.0; SOT-223-3_TabPin2; LCSC Part C6187
U3: DS18B20; TO-92_Inline; LCSC Part C20611523; not fitted
U4: AMS1117-3.3; SOT-223-3_TabPin2; LCSC Part C6186
U5: Mini360; mini360
U6: TSOP1838; TSOP18XX
U7: ESP-12F; ESP-12E_no_pins
U8: PJ-320A; LCSC Part C2884926
U9: 4051; SOP-16_3.9x9.9mm_P1.27mm; not fitted
U11: SIM800L-CORE
dc-in1: 5.5PowerIn; PARTREV A
display/ads1: Conn_01x04_Pin; PinHeader_1x04_P2.54mm_Vertical; not fitted
max1: PinHeader_1x05_P2.54mm_Vertical; not fitted
prog1: prog; PinHeader_1x04_P2.54mm_Vertical

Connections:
+3.3V: C2.1, D5.2 (A), D9.1 (A1), J6.5, Q1.2 (E), Q3.2 (E), Q5.2 (E), Q7.2 (E), R5.1, R6.1, R8.2, R27.1, U4.2 (VO), U7.8 (VCC), U11.2 (VCC)
+5C: C1.1, C3.1, D1.1 (A1), D7.2 (A), J1.1, J6.4, MX-RM-5V-RF-sensor1.1, R3.2, R11.1, U2.2 (VO), U3.3 (V_{DD}), U4.3 (VI), U5.4 (OUT+), U6.VCC (V+), U9.16 (VDD), display/ads1.3, max1.2, prog1.1
+12C: D4.1 (A1), F1.2, J6.3, U2.3 (VI), U5.2 (IN+)
/a0: R29.2, U7.2 (ADC), U8.1 (Sleeve)
/d0: JP13.2 (C), U7.4 (GPIO16)
/d0-com-8: J5.8, JP13.3 (B), K3.COM
/d0-nc-9: J5.9, K3.NC
/d0-no-7: J5.7, K3.NO
/d1: J6.6, R19.2, SW1.1 (C), U7.20 (GPIO5), display/ads1.1
/d2: J6.7, R14.2, U7.19 (GPIO4), display/ads1.2
/d3: J4-flash1.2, JP12.2 (C), R8.1, R22.1, U7.18 (GPIO0)
/d3-com-11: J5.11, JP12.3 (B), K1.COM
/d3-nc-12: J5.12, K1.NC
/d3-no-10: J5.10, K1.NO
/d4: J6.8, R3.1, R12.1, U3.2 (DQ), U7.17 (GPIO2)
/d5: R26.1, R31.2, U7.5 (GPIO14), U9.11 (A), U11.5 (TXD), max1.3
/d6: R16.1, R33.1, R35.2, U7.6 (GPIO12), U9.10 (B), max1.5
/d7: MX-RM-5V-RF-sensor1.2, MX-RM-5V-RF-sensor1.3, R17.1, R24.2, U7.7 (GPIO13), U9.9 (C)
/d8: R9.1, R25.2, R30.1, U7.16 (GPIO15), max1.4
/mosf1-out-d5: J6.9, Q9.7 (D1), Q9.8 (D1), R31.1
/mosf1-out-d6: J6.10, Q9.5 (D2), Q9.6 (D2), R35.1
/mosf1-out-d7: Q10.7 (D1), Q10.8 (D1), R24.1
/mosf1-out-d8: Q10.5 (D2), Q10.6 (D2)
/mosf2-out-d7: J6.11
/pwrRel: D2.1 (K), D3.1 (K), D6.1 (K), D8.1 (K), J1.2, K1.A1, K2.A1, K3.A1, K4.A1
/rx: D14.1 (K), JP3.2 (C), U7.21 (GPIO3/RXD), prog1.4
/rx-com-5: J5.5, JP3.3 (B), K4.COM
/rx-nc-6: J5.6, K4.NC
/rx-no-4: J5.4, K4.NO
/tx: D13.1 (K), JP1.2 (C), U7.22 (GPIO1/TXD), prog1.3
/tx-com-2: J5.2, JP1.3 (B), K2.COM
/tx-nc-3: J5.3, K2.NC
/tx-no-1: J5.1, K2.NO
GND: C1.2, C2.2, C3.2, C4.2, D1.2 (A2), D4.2 (A2), D9.2 (A2), D13.2 (A), D14.2 (A), J2.2, J4-flash1.1, J6.1, J6.2, MX-RM-5V-RF-sensor1.4, Q2.2 (E), Q4.2 (E), Q6.2 (E), Q8.2 (E), Q9.1 (S1), Q9.3 (S2), Q10.1 (S1), Q10.3 (S2), R9.2, R15.2, R21.1, R28.2, R32.1, R34.1, SW1.2 (D), SW2-flash1.1 (C), SW2-reset1.1 (C), U1.4 (GND), U2.1 (GND), U3.1 (GND), U4.1 (GND), U5.1 (IN-), U5.3 (OUT-), U6.GND, U7.15 (GND), U9.6 (Inh), U9.7 (VEE), U9.8 (VSS), dc-in1.B, dc-in1.C, display/ads1.4, max1.1, prog1.2
GNDPWR: R23.2, U11.6 (GND)
unnamed: D2.2 (A), K1.A2, Q2.3 (C)
unnamed: D3.2 (A), K2.A2, Q4.3 (C)
unnamed: D5.1 (K), R14.1
unnamed: D6.2 (A), K3.A2, Q6.3 (C)
unnamed: D7.1 (K), R15.1
unnamed: D8.2 (A), K4.A2, Q8.3 (C)
unnamed: D10.2 (A), R26.2
unnamed: D10.1 (K), Q9.2 (G1), R32.2
unnamed: D11.2 (A), R33.2
unnamed: D11.1 (K), Q9.4 (G2), R34.2
unnamed: D15.2 (A), R17.2
unnamed: D15.1 (K), Q10.2 (G1), R21.2
unnamed: F1.1, dc-in1.A
unnamed: J6.12, R25.1
unnamed: JP1.1 (A), R4.2
unnamed: JP3.1 (A), R18.2
unnamed: JP12.1 (A), R1.2
unnamed: JP13.1 (A), R10.2
unnamed: Q1.1 (B), R1.1
unnamed: Q1.3 (C), R2.2
unnamed: Q2.1 (B), R2.1
unnamed: Q3.1 (B), R4.1
unnamed: Q3.3 (C), R7.2
unnamed: Q4.1 (B), R7.1
unnamed: Q5.1 (B), R10.1
unnamed: Q5.3 (C), R13.2
unnamed: Q6.1 (B), R13.1
unnamed: Q7.1 (B), R18.1
unnamed: Q7.3 (C), R20.2
unnamed: Q8.1 (B), R20.1
unnamed: Q10.4 (G2), R30.2
unnamed: R19.1, U6.OUT
unnamed: R22.2, SW2-flash1.2 (D)
unnamed: J2.1, R5.2, SW2-reset1.2 (D), U7.1 (~RST)
unnamed: R12.2, U1.2 (DATA)
unnamed: R11.2, U1.1 (VDD)
unnamed: R6.2, U7.3 (EN)
unnamed: C4.1, R27.2, R28.1, R29.1, U8.2 (Tip)
unnamed: R16.2, R23.1, U11.4 (RXD)

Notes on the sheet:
отметить элементы которые опциональны к установке перепроверить выводы зеленых коннекторов - подписи поставить ПВМ как инпуты для переключения инфракарсный передатчик управление не плюсом, а минусом проверить есть ли отправка ИК сигнала при инверсном подклчюении
If we want to detect GND, the contact of base mosfet should go to additional input

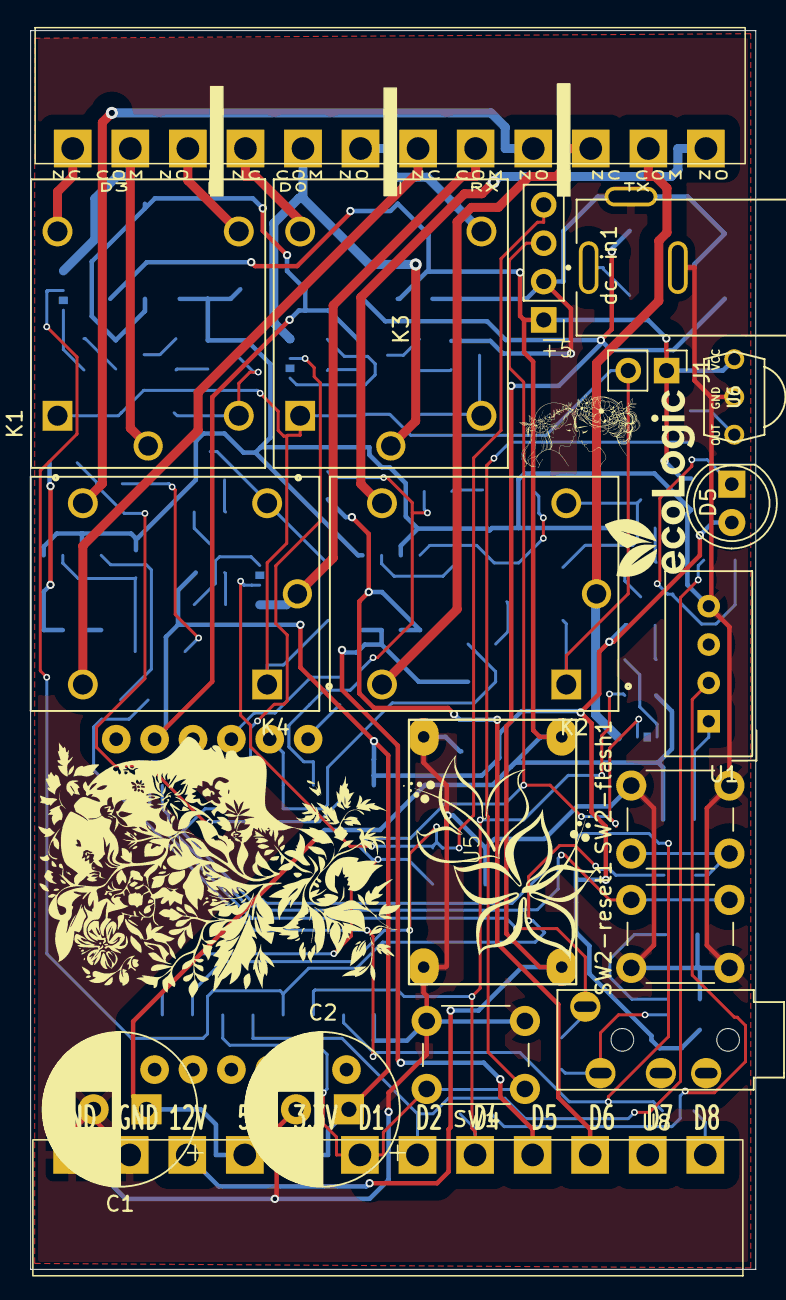
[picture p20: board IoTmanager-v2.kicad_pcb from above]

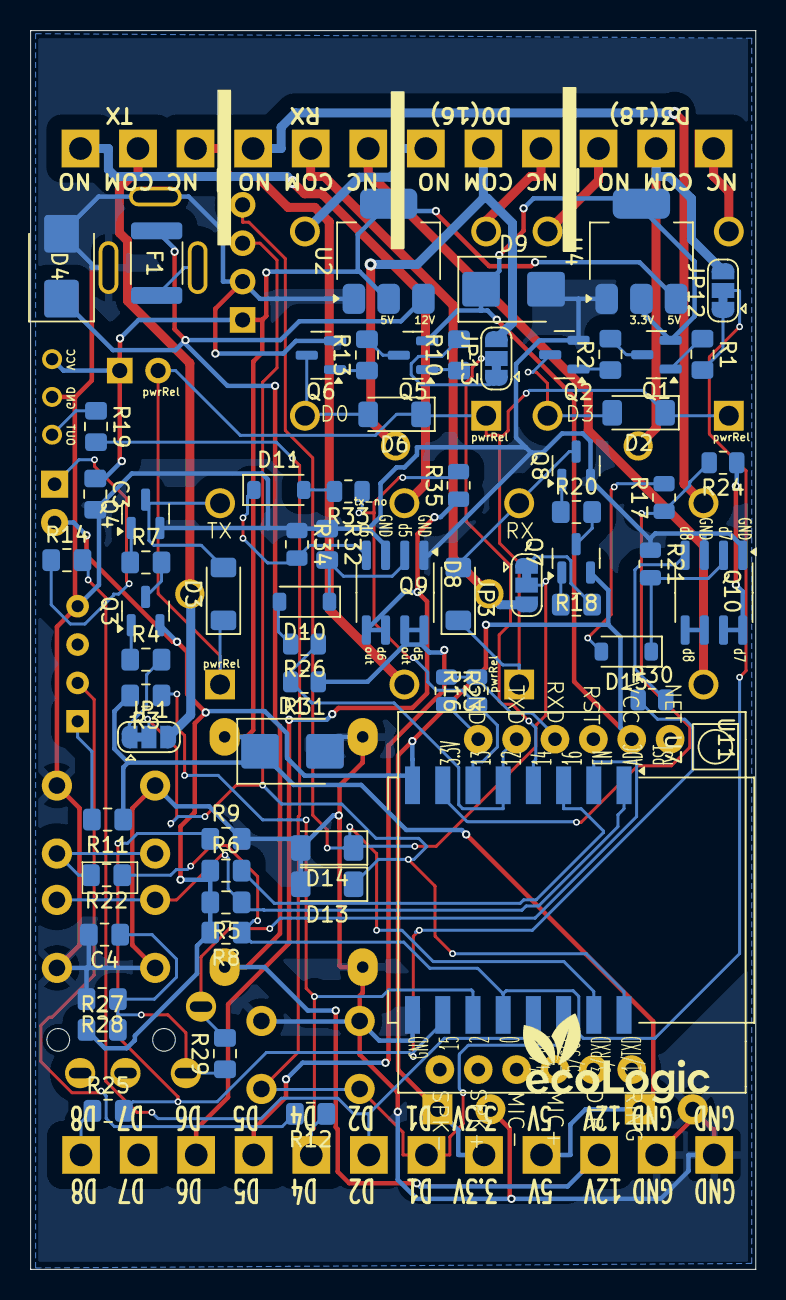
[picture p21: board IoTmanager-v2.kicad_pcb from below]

Board: 2 copper layers, 48.0 x 82.0 mm, 91 parts (68 on the bottom side), 72 nets.

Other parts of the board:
G2, G3: LOGO
flowers: LOGO
woman: LOGO
womans: LOGO

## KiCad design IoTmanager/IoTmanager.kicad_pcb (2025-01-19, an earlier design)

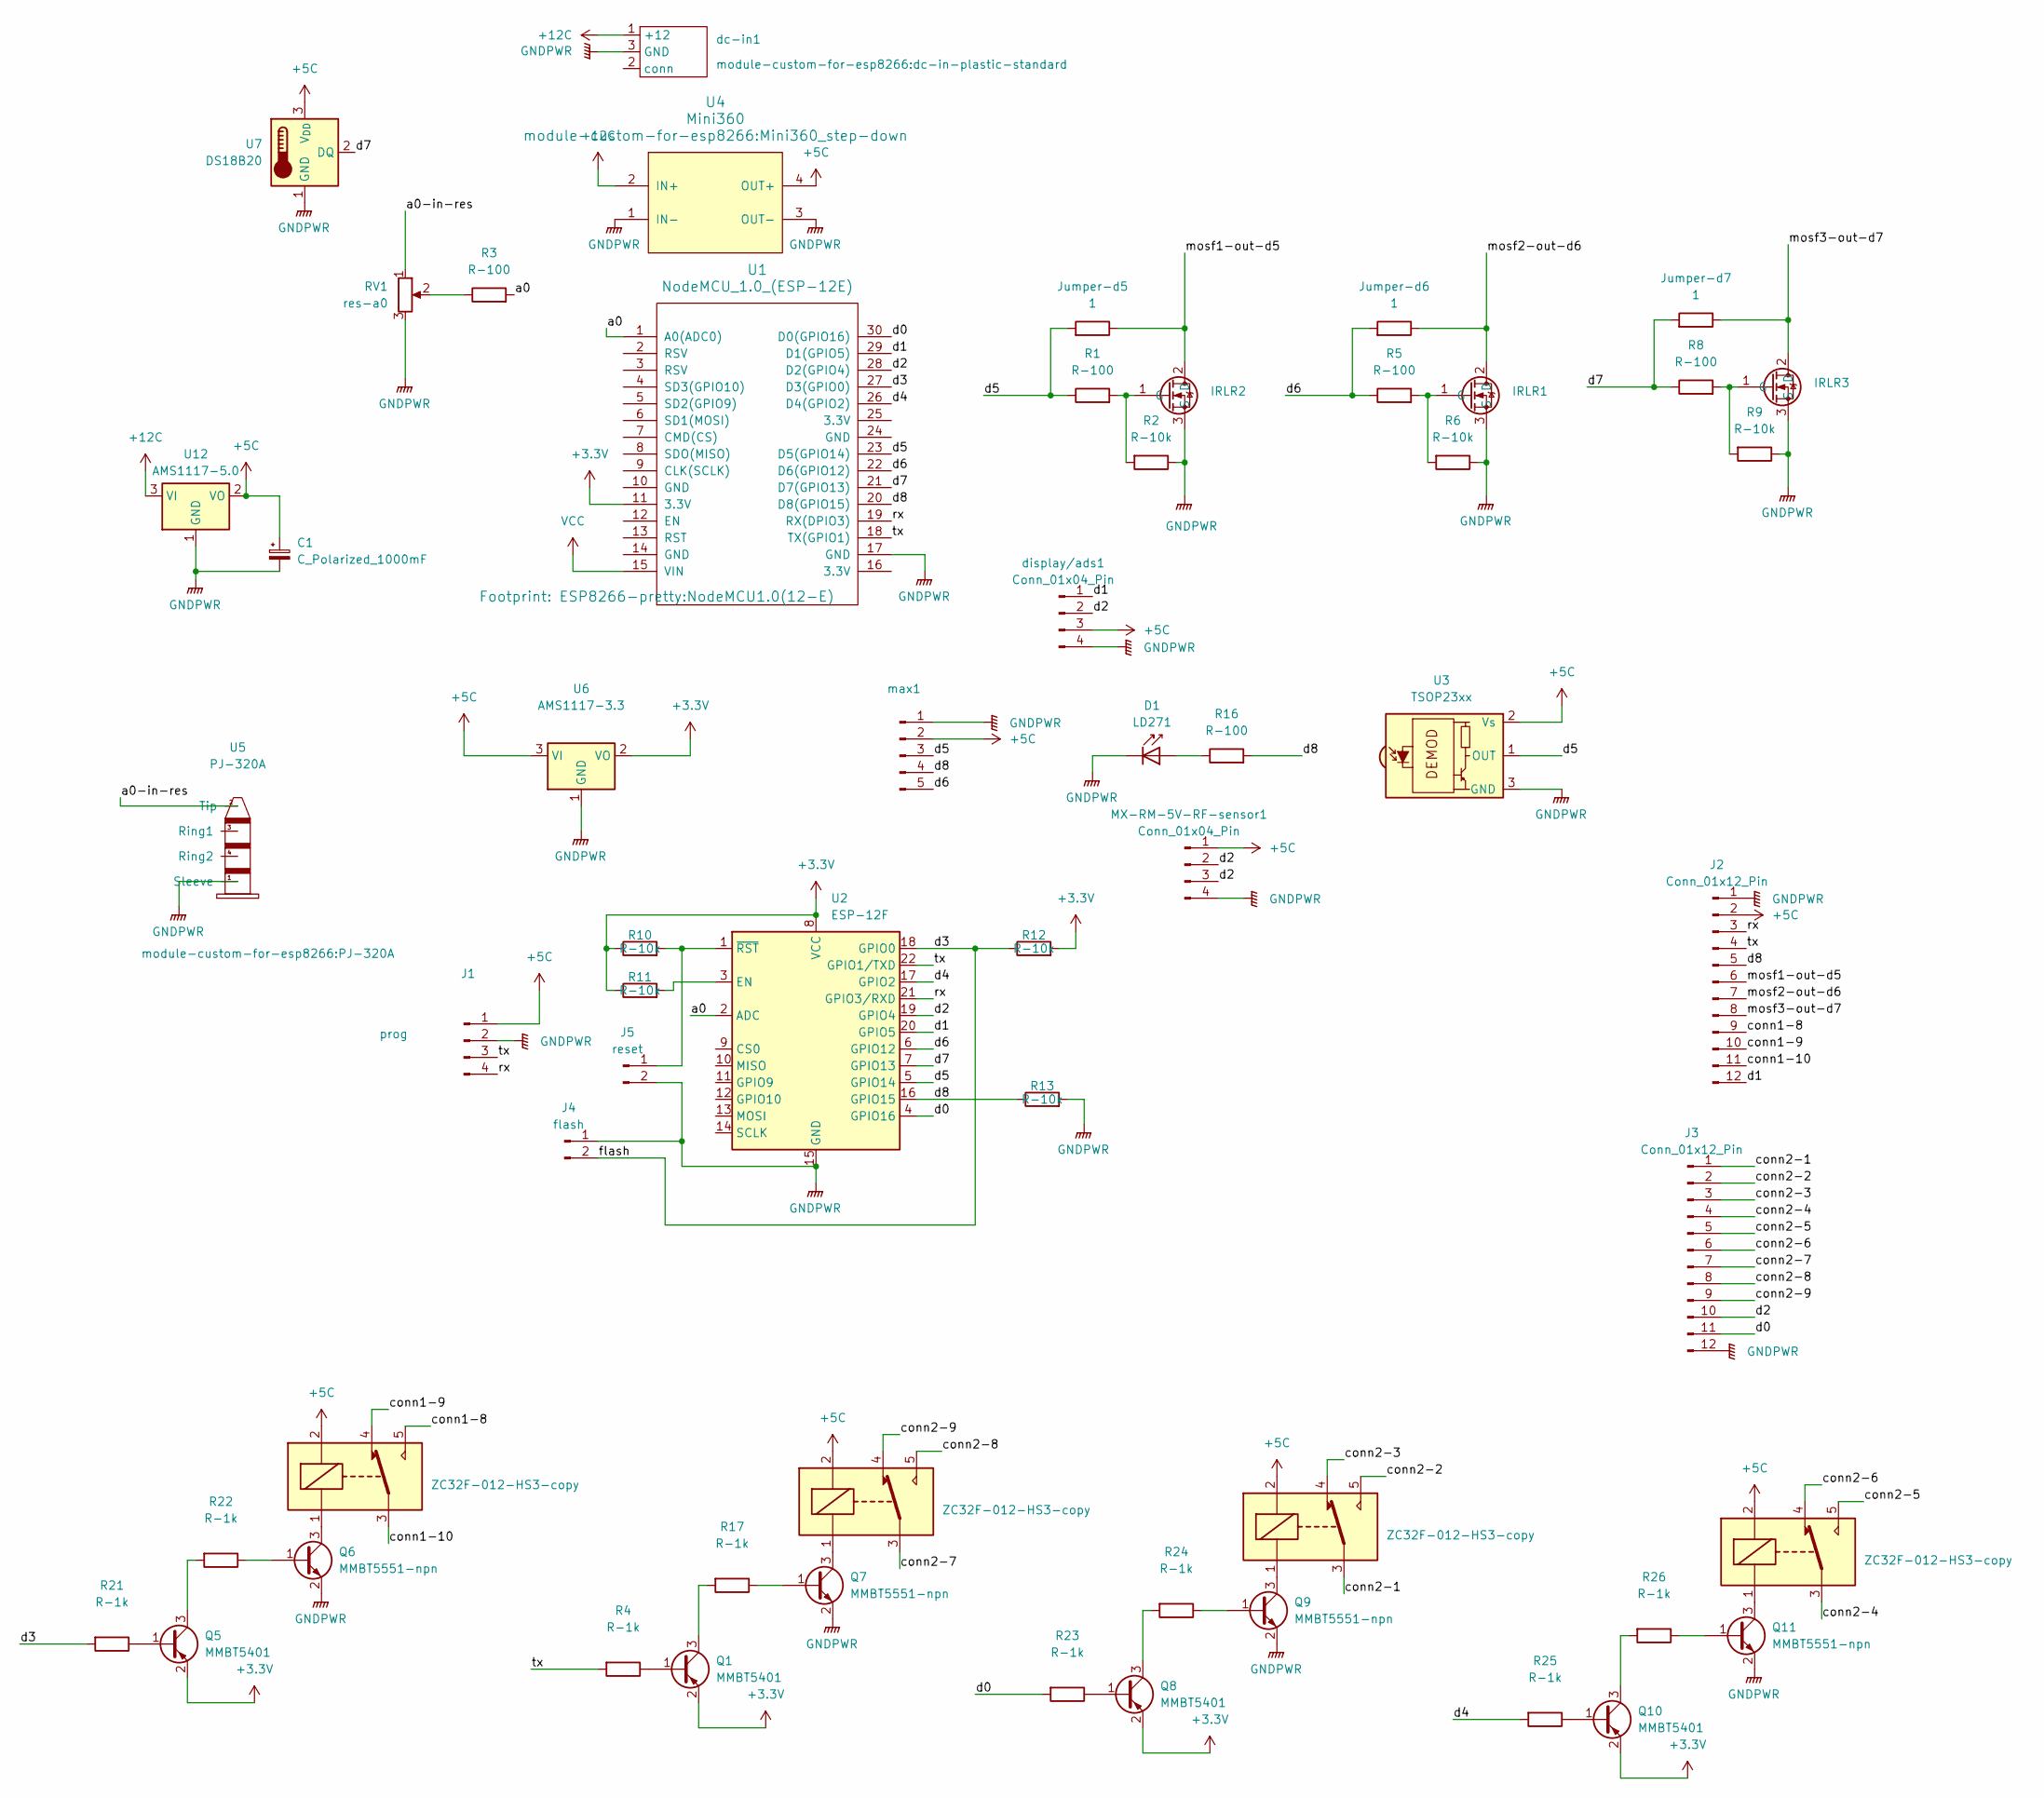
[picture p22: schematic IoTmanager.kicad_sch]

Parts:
C1: C_Polarized_1000mF; CP_Radial_D10.0mm_P3.50mm
D1: LD271; LED_D5.0mm_IRGrey
IRLR1, IRLR2, IRLR3: TO-252-2
J1: prog; PinHeader_1x04_P2.54mm_Vertical
J2, J3: Conn_01x12_Pin; connector-12-green-mini
J4: flash; PinHeader_1x02_P2.54mm_Vertical
J5: reset; PinHeader_1x02_P2.54mm_Vertical
Jumper-d5, Jumper-d6, Jumper-d7: 1; R_0805_2012Metric
K3, K5, K6, K7: ZC32F-012-HS3-copy; ZC32F-012-HS3
MX-RM-5V-RF-sensor1: Conn_01x04_Pin; RF_Receiver_433_MHz
Q1, Q5, Q8, Q10: MMBT5401; SOT-23; LCSC Part C8326
Q6, Q7, Q9, Q11: MMBT5551-npn; SOT-23; LCSC Part C2145
R1, R3, R5, R8, R16: R-100; R_0805_2012Metric; LCSC Part C17408
R2, R6, R9, R10, R11, R12, R13: R-10k; R_0805_2012Metric; LCSC Part C17414
R4, R17, R21, R22, R23, R24, R25, R26: R-1k; R_0805_2012Metric; LCSC Part C25905
RV1: res-a0; Potentiometer_Bourns_3266Y_Vertical
U1: NodeMCU_1.0_(ESP-12E); NodeMCU1.0(12-E)
U2: ESP-12F; ESP-12E
U3: TSOP23xx; Vishay_MOLD-3Pin
U4: Mini360; Mini360_step-down
U5: PJ-320A; LCSC Part C2884926
U6: AMS1117-3.3; SOT-223-3_TabPin2; LCSC Part C6186
U7: DS18B20; TO-92_Inline; LCSC Part C20611523
U12: AMS1117-5.0; SOT-223-3_TabPin2; LCSC Part C6187
dc-in1: dc-in-plastic-standard
display/ads1: Conn_01x04_Pin; PinHeader_1x04_P2.54mm_Vertical
max1: PinHeader_1x05_P2.54mm_Vertical

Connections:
+3.3V: Q1.2 (E), Q5.2 (E), Q8.2 (E), Q10.2 (E), R10.1, R11.1, R12.2, U1.11 (3.3V), U2.8 (VCC), U6.2 (VO)
+5C: C1.1, J1.1, J2.2, K3.2, K5.2, K6.2, K7.2, MX-RM-5V-RF-sensor1.1, U3.2 (Vs), U4.4 (OUT+), U6.3 (VI), U7.3 (V_{DD}), U12.2 (VO), display/ads1.3, max1.2
+12C: U4.2 (IN+), U12.3 (VI), dc-in1.1 (+12)
/a0: R3.2, U1.1 (A0(ADC0)), U2.2 (ADC)
/a0-in-res: RV1.1, U5.2 (Tip)
/conn1-8: J2.9, K3.5
/conn1-9: J2.10, K3.4
/conn1-10: J2.11, K3.3
/conn2-1: J3.1, K6.3
/conn2-2: J3.2, K6.5
/conn2-3: J3.3, K6.4
/conn2-4: J3.4, K7.3
/conn2-5: J3.5, K7.5
/conn2-6: J3.6, K7.4
/conn2-7: J3.7, K5.3
/conn2-8: J3.8, K5.5
/conn2-9: J3.9, K5.4
/d0: J3.11, R23.2, U1.30 (D0(GPIO16)), U2.4 (GPIO16)
/d1: J2.12, U1.29 (D1(GPIO5)), U2.20 (GPIO5), display/ads1.1
/d2: J3.10, MX-RM-5V-RF-sensor1.2, MX-RM-5V-RF-sensor1.3, U1.28 (D2(GPIO4)), U2.19 (GPIO4), display/ads1.2
/d3: J4.2, R12.1, R21.2, U1.27 (D3(GPIO0)), U2.18 (GPIO0)
/d4: R25.2, U1.26 (D4(GPIO2)), U2.17 (GPIO2)
/d5: Jumper-d5.1, R1.1, U1.23 (D5(GPIO14)), U2.5 (GPIO14), U3.1 (OUT), max1.3
/d6: Jumper-d6.1, R5.1, U1.22 (D6(GPIO12)), U2.6 (GPIO12), max1.5
/d7: Jumper-d7.1, R8.1, U1.21 (D7(GPIO13)), U2.7 (GPIO13), U7.2 (DQ)
/d8: J2.5, R13.1, R16.2, U1.20 (D8(GPIO15)), U2.16 (GPIO15), max1.4
/mosf1-out-d5: IRLR2.2 (D), J2.6, Jumper-d5.2
/mosf2-out-d6: IRLR1.2 (D), J2.7, Jumper-d6.2
/mosf3-out-d7: IRLR3.2 (D), J2.8, Jumper-d7.2
/rx: J1.4, J2.3, U1.19 (RX(DPIO3)), U2.21 (GPIO3/RXD)
/tx: J1.3, J2.4, R4.2, U1.18 (TX(GPIO1)), U2.22 (GPIO1/TXD)
GNDPWR: C1.2, D1.1 (K), IRLR1.3 (S), IRLR2.3 (S), IRLR3.3 (S), J1.2, J2.1, J3.12, J4.1, J5.2, MX-RM-5V-RF-sensor1.4, Q6.2 (E), Q7.2 (E), Q9.2 (E), Q11.2 (E), R2.1, R6.1, R9.1, R13.2, RV1.3, U1.17 (GND), U2.15 (GND), U3.3 (GND), U4.1 (IN-), U4.3 (OUT-), U5.1 (Sleeve), U6.1 (GND), U7.1 (GND), U12.1 (GND), dc-in1.3 (GND), display/ads1.4, max1.1
unnamed: D1.2 (A), R16.1
unnamed: IRLR1.1 (G), R5.2, R6.2
unnamed: IRLR2.1 (G), R1.2, R2.2
unnamed: IRLR3.1 (G), R8.2, R9.2
unnamed: J5.1, R10.2, U2.1 (~RST)
unnamed: Q1.1 (B), R4.1
unnamed: Q1.3 (C), R17.2
unnamed: Q5.1 (B), R21.1
unnamed: Q5.3 (C), R22.2
unnamed: Q6.1 (B), R22.1
unnamed: K3.1, Q6.3 (C)
unnamed: Q7.1 (B), R17.1
unnamed: K5.1, Q7.3 (C)
unnamed: Q8.1 (B), R23.1
unnamed: Q8.3 (C), R24.2
unnamed: Q9.1 (B), R24.1
unnamed: K6.1, Q9.3 (C)
unnamed: Q10.1 (B), R25.1
unnamed: Q10.3 (C), R26.2
unnamed: Q11.1 (B), R26.1
unnamed: K7.1, Q11.3 (C)
unnamed: R3.1, RV1.2
unnamed: R11.2, U2.3 (EN)

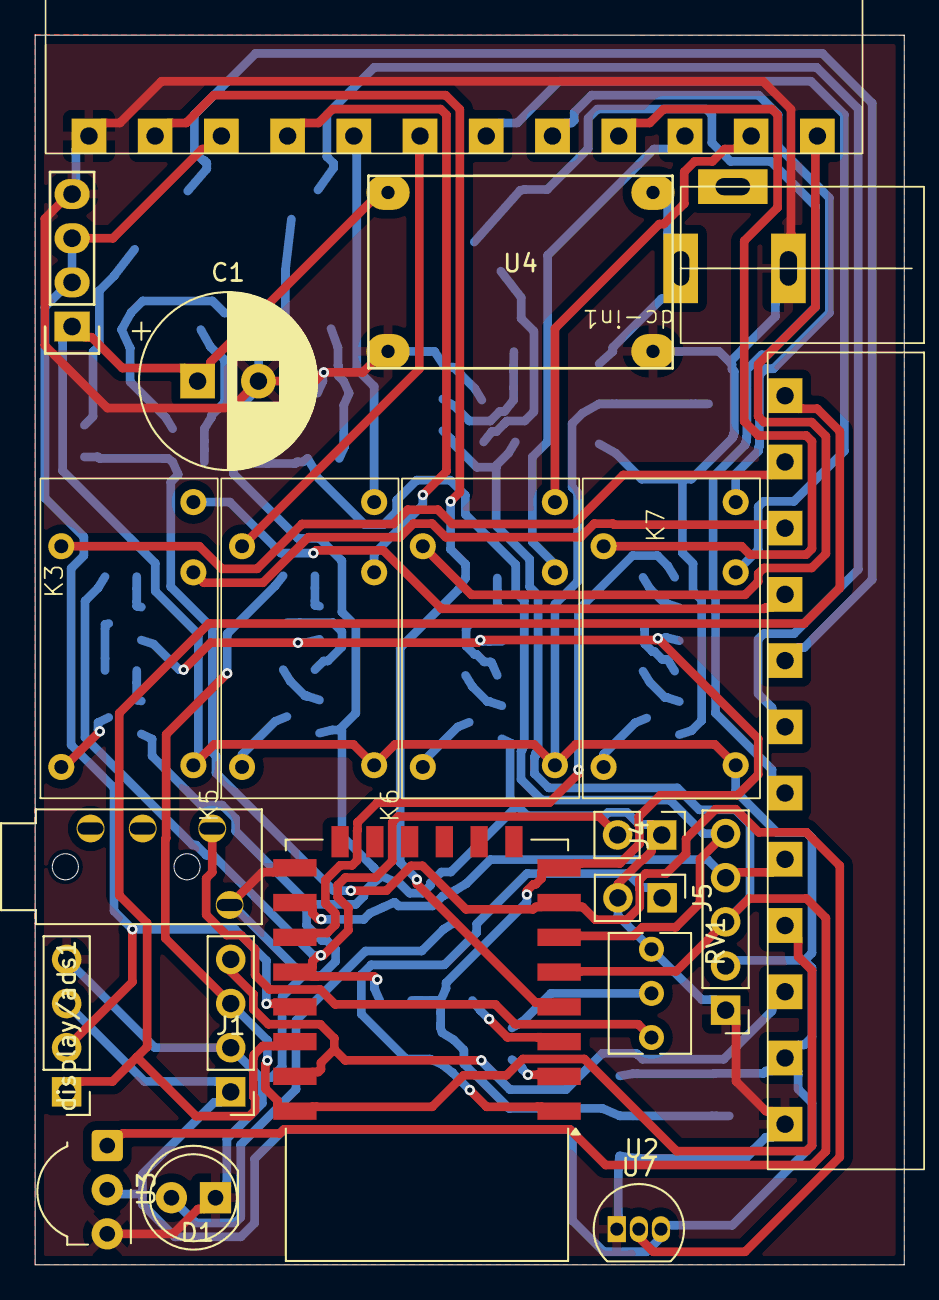
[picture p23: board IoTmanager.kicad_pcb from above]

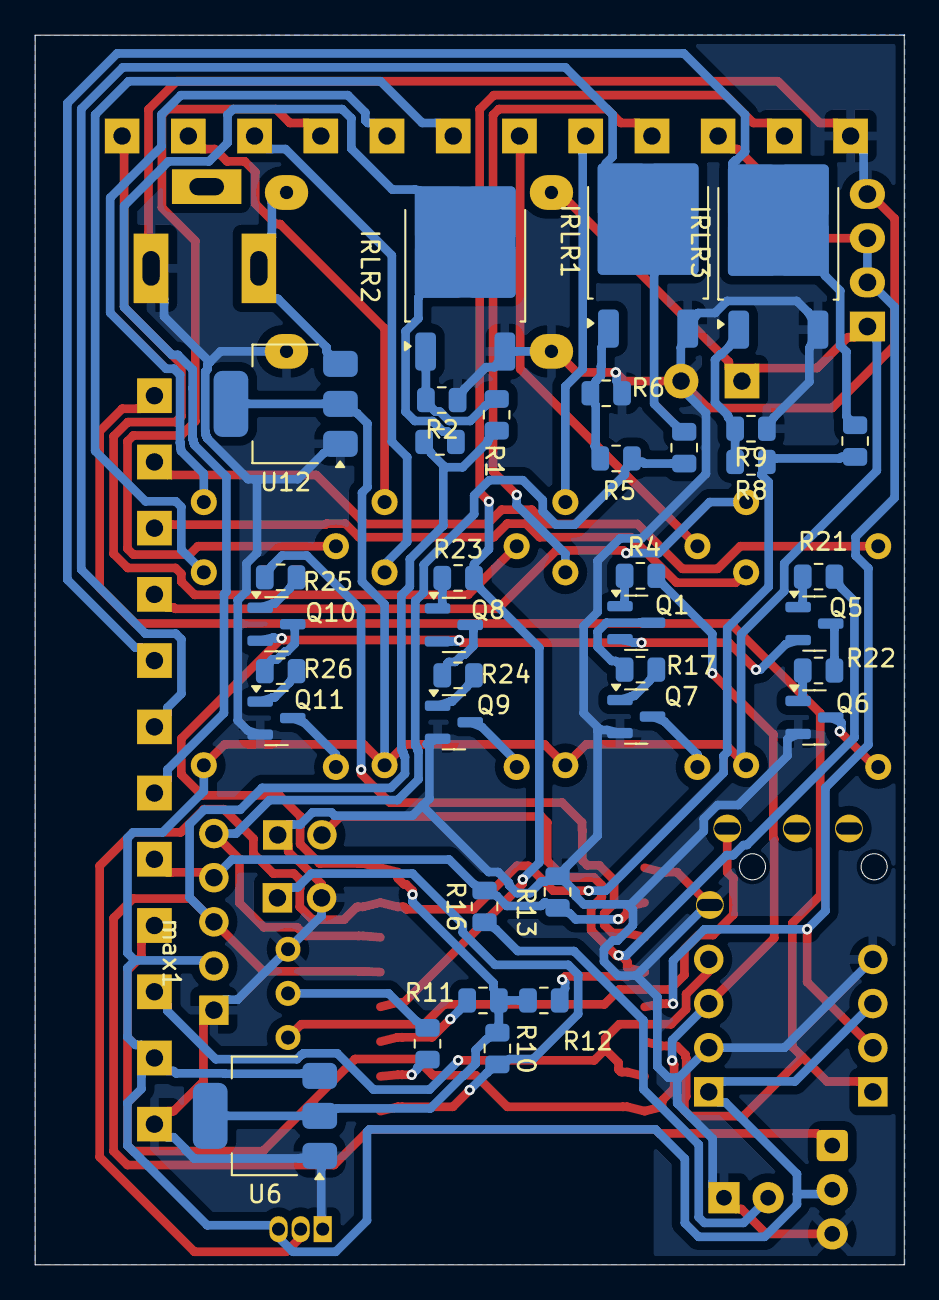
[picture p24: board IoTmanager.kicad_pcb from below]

Board: 2 copper layers, 50.0 x 70.7 mm, 57 parts (36 on the bottom side), 55 nets.

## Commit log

2025-05-24 Update IoTmanager schematic and libraries
    - Changed paper size from A3 to A2 in IoTmanager schematic.
    - Added MMDT4413-7-F symbol and footprint to the schematic and libraries.
    - Updated various component properties including reference, value, and footprint.
    - Adjusted component placements and added new power symbols for +3.3V and GNDPWR.
    - Modified existing project files in Proteous tests, including autosaved versions.
    - Updated fp-info-cache with new component details.
    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
    [IoTmanager-v2.kicad_pcb, IoTmanager-v2.kicad_sch]
2025-05-30 auto update from EPAM computer
    [IoTmanager-v2.kicad_sch]
2025-06-16 Update fp-info-cache with new audio module and relay specifications
    - Updated the ID for the Audio_Module entry.
    - Added new relay module (RELAY_SRD-05VDC-SL-C) with specifications.
    - Ensured proper formatting and consistency in the module entries.
    [IoTmanager-v2.kicad_pcb, IoTmanager-v2.kicad_sch]
2025-07-02 Remove obsolete libraries and files for various components including SX1308, EasyDriver, TBD62783, TLE5205, TLP627, TP4056, XL4015, and PJ-320A. This cleanup includes the deletion of associated docum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
    [SIM800L v10.step, SW-TH_4P-L6.0-W6.0-P4.50-LS6.5.pcbdoc]
2025-07-28 Add new schematic images for IoT manager
2025-07-28 Add new images for IoT manager: plate.png and plate2.png
2025-08-22 Добавить README.md с описанием проекта и инструкциями по сборке
2025-09-25 update .gitignore to exclude autoroute files and include gerber2.zip
    [BOM.csv]
2025-10-04 net and print
    [IoTmanager-v2.kicad_pcb, IoTmanager-v2.kicad_sch]
2025-10-05 fixed d4
    [IoTmanager-v2.kicad_pcb, IoTmanager-v2.kicad_sch]
2025-10-19 route design
    [BOM.csv, IoTmanager-v2.kicad_pcb, IoTmanager-v2.kicad_sch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]
2025-10-22 moved schema
    [IoTmanager-v2.kicad_sch]
2025-11-09 bom updates and xls
    [BOM.csv, BOM.xlsx]
2025-11-15 wire connectio scheduler
2025-11-22 new route
    [IoTmanager-v2.kicad_pcb, IoTmanager-v2.kicad_sch, IoTmanager_v3.dsn]
2025-11-22 rx tx without resistor
    [IoTmanager-v2.kicad_sch]
2025-11-23 IR fix contact
    [IoTmanager-v2.kicad_pcb, IoTmanager-v2.kicad_sch]
2025-12-01 new gerber and changes in positions
    [BOM-jlcpcb.xlsx, BOM.csv, BOM.xlsx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]
2025-12-03 3d parametres
    [chatgpt_ref.csv, user_reference.csv]
2026-03-01 update in wires
    [IoTmanager-v2.kicad_pcb, IoTmanager-v2.kicad_sch]
2026-05-07 added sim800
    [IoTmanager-v2.kicad_pcb, IoTmanager-v2.kicad_sch]
2026-05-17 fixed route for d1 input
    [IoTmanager-v2.kicad_pcb, IoTmanager-v2.kicad_sch, IoTmanager_v2.dsn]
2026-05-17 investigate input output
    [IoTmanager-v2.kicad_sch]
2026-05-17 trasnsitors and inputs
    [IoTmanager-v2.kicad_pcb, IoTmanager-v2.kicad_sch]
2026-06-26 fixed lables
    [IoTmanager-v2.csv, IoTmanager-v2.kicad_pcb, IoTmanager-v2.kicad_sch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]
